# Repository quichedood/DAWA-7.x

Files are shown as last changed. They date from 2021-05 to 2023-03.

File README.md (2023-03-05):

# DAWA-7.x

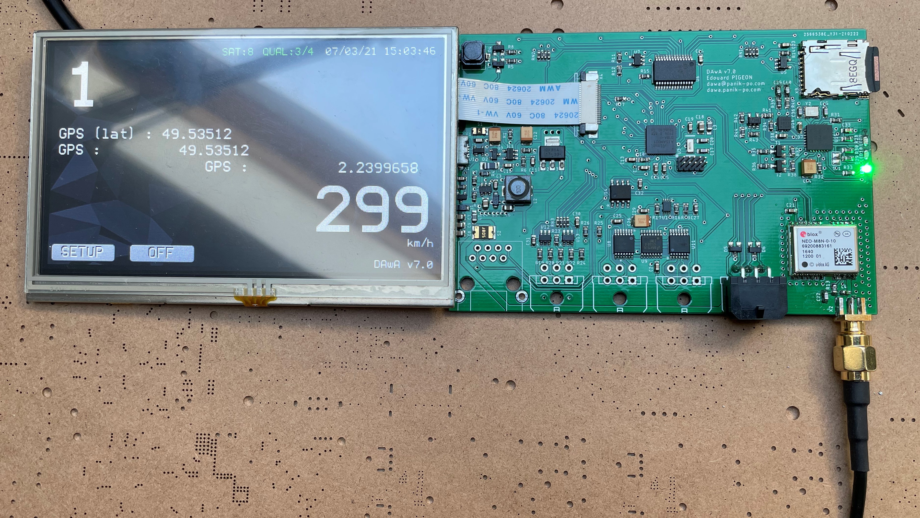
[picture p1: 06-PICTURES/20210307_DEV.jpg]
DAWA7


Démo : https://youtu.be/l66AxoFr9uk

DAWA est un système de chronométrage et d'acquisition de données pour votre moto.
Il enregistre les données 10 fois par seconde dans un fichier CSV.

Specs/fonctionnalités :
- Ecran TFT tactile 4,3" couleur (resistif)
- Carte micro SD
- Antenne GPS externe
- Alimentation externe via batterie 12v
- Indicateur 8 leds paramétrable
- Position GPS (10Hz)
- Chronométrage circuit
- 2 entrées numériques (binaire)
- 2 entrées numériques (signal carré, fréquence)
- 8 entrées analogiques
- 6 capteurs de température infrarouge
- Module OBD (prise diagnostique)

Exemple de mesures :
- Vitesse (GPS ou basé sur une entrée numérique)
- Rapport de vitesse engagé (basé sur une entrée analogique)
- Régime moteur (basé sur une entrée numérique)
- Capteur de pression de frein (basé sur une entrée analogique)

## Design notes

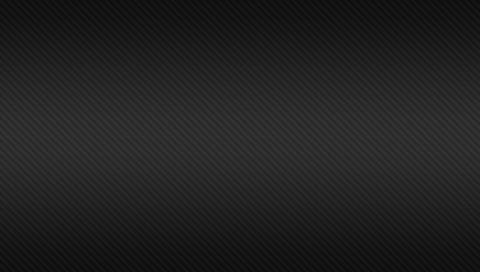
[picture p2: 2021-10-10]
05-EVE/EAB/Pictures/carbon_480x272_COMPRESSED_RGBA_ASTC_4x4_KHR_Converted.png

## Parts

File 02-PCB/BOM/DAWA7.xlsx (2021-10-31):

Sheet: Feuil1
Qty | Stock Perso | Ex | Line Item | Manufacturer | MPN | Schematic Reference | Description | Unit price Mouser | Stock Mouser | Datasheet
1 | 7 | 7 | LM2734YMK/NOPB | Texas Instruments | LM2734YMK/NOPB | U2 |  | !!! Processing !!! | !!! Processing !!! | !!! Processing !!!
1 | 9 | 9 | ADC128D818CIMTX/NOPB | Texas Instruments | ADC128D818CIMTX/NOPB | U9 |  | !!! Processing !!! | !!! Processing !!! | !!! Processing !!!
1 | 15 | 15 | SKPMAPE010 | ALPS | SKPMAPE010 | S3 |  | !!! Processing !!! | !!! Processing !!! | !!! Processing !!!
1 | 50 | 50 | 0432028816 | Molex | 43202-8816 | X6 |  | !!! Processing !!! | !!! Processing !!! | !!! Processing !!!
1 | 6 | 6 | MCP2562T-E/MF | Microchip | MCP2562T-E/MF | U16 | 1/1 Transceiver Half CANbus 8-DFN (3x3) | !!! Processing !!! | !!! Processing !!! | ERROR: Unauthorized Access. Please email contact@octopart.com for assistance.
1 | 20 | 20 | MC33269ST-3.3T3G | ON Semiconductor | MC33269ST-3.3T3G | IC2 | Adjustable Output Low Dropout Voltage Regulator 800 mA | !!! Processing !!! | !!! Processing !!! | !!! Processing !!!
1 | 0 | 0 | ATSAMD21G18A-MFT | Microchip | ATSAMD21G18A-MFT | U3 | Atmel SAMD21G SMART ARM-Based Microcontroller | !!! Processing !!! | !!! Processing !!! | !!! Processing !!!
1 | 9 | 9 | PESD1CAN,215 | Nexperia | PESD1CAN,215 | D6 | CAN bus ESD protection diode | !!! Processing !!! | !!! Processing !!! | !!! Processing !!!
2 | 18 | 9 | C0603C561J5GACTU | KEMET | C0603C561J5GACTU | C39, C40 | CAPACITOR, European symbol | !!! Processing !!! | !!! Processing !!! | !!! Processing !!!
6 | 100 | 16 | C0805C106K4PAC7210 | KEMET | C0805C106K4PAC7210 | C4, C6, C7, C8, C9, C18 | CAPACITOR, European symbol | !!! Processing !!! | !!! Processing !!! | !!! Processing !!!
4 | 100 | 25 | C0603C220K4GACTU | KEMET | C0603C220K4GACTU | C17, C20, C35, C36 | CAPACITOR, European symbol | !!! Processing !!! | !!! Processing !!! | !!! Processing !!!
16 | 500 | 31 | C0603C104M4RAC7411 | KEMET | C0603C104M4RAC7411 | C10, C11, C13, C14, C15, C16, C19, C23, C24, C25, C28, C29, C30, C31, C32, C33 | CAPACITOR, European symbol | !!! Processing !!! | !!! Processing !!! | !!! Processing !!!
3 | 100 | 33 | C0603C103K3RAC7411 | KEMET | C0603C103K3RAC7411 | C1, C3, C5 | CAPACITOR, European symbol | !!! Processing !!! | !!! Processing !!! | !!! Processing !!!
2 | 100 | 50 | C0603C105K4RAC7411 | KEMET | C0603C105K4RAC7411 | C37, C38 | CAPACITOR, European symbol | !!! Processing !!! | !!! Processing !!! | !!! Processing !!!
1 | 100 | 100 | C0603C475K9PAC7411 | KEMET | C0603C475K9PAC7411 | C21 | CAPACITOR, European symbol | !!! Processing !!! | !!! Processing !!! | !!! Processing !!!
1 | 100 | 100 | C0603C470G3HACTU | KEMET | C0603C470G3HACTU | C22 | CAPACITOR, European symbol | !!! Processing !!! | !!! Processing !!! | !!! Processing !!!
1 | 100 | 100 | C0603C101K5GACTU | KEMET | C0603C101K5GACTU | C27 | CAPACITOR, European symbol | !!! Processing !!! | !!! Processing !!! | !!! Processing !!!
1 | 10 | 10 | CM7V-T1A-32.768kHz-9pF-100PPM-TA-QC | Micro Crystal | CM7V-T1A-32.768KHZ-9PF-100PPM-TA-QC | Y1 | CM7V-T1A Tuning Fork Crystal 32.768 kHz | !!! Processing !!! | !!! Processing !!! | !!! Processing !!!
1 | 10 | 10 | DM3AT-SF-PEJM5 | Hirose | DM3AT-SF-PEJM5 | X3 | CONN MICRO SD R/A PUSH-PUSH SMD | !!! Processing !!! | !!! Processing !!! | !!! Processing !!!
1 | 10 | 10 | 3000TR | Keystone | 3000TR | B1 | CR1216/CR1220/CR1225 12mm 3V lithium coin cell | !!! Processing !!! | !!! Processing !!! | !!! Processing !!!
2 | 100 | 50 | 742C083101JP | CTS Components | 742C083101JP | RN1, RN2 | CTS 742 Series | !!! Processing !!! | !!! Processing !!! | !!! Processing !!!
1 | 100 | 100 | 742C083511JP | CTS Components | 742C083511JP | RN3 | CTS 742 Series | !!! Processing !!! | !!! Processing !!! | !!! Processing !!!
2 | 9 | 4 | MBR120ESFT3G | ON Semiconductor | MBR120ESFT3G | D1, D3 | Diode | !!! Processing !!! | !!! Processing !!! | !!! Processing !!!
1 | 9 | 9 | CD1206-S01575 | Bourns | CD1206-S01575 | D2 | DIODE | !!! Processing !!! | !!! Processing !!! | !!! Processing !!!
1 | 20 | 20 | P82B96DR | Texas Instruments | P82B96DR | U14 | DUAL BIDIRECTIONAL BUS BUFFER | !!! Processing !!! | !!! Processing !!! | !!! Processing !!!
1 | 0 | 0 | MMBZ27VALT3G | ON Semiconductor | MMBZ27VALT3G | D5 | Dual Common Anode Zeners | !!! Processing !!! | ERROR: Unauthorized Access. Please email contact@octopart.com for assistance. | !!! Processing !!!
2 | 14 | 7 | SN74LVC2G17DBVR | Texas Instruments | SN74LVC2G17DBVR | U12, U13 | DUAL SCHMITT-TRIGGER BUFFER | !!! Processing !!! | !!! Processing !!! | !!! Processing !!!
1 | 20 | 20 | 687120149022 | Würth Elektronik | 687120149022 | X4 | FFC/FPC-to-Board 0.50mm (.020p) SMT Top Contact | !!! Processing !!! | !!! Processing !!! | !!! Processing !!!
1 | 7 | 7 | LMV321M5X/NOPB | Texas Instruments | LMV321M5X/NOPB | IC1 | General Purpose, Low Voltage, Rail-to-Rail Output Operational Amplifiers | !!! Processing !!! | !!! Processing !!! | !!! Processing !!!
1 | 10 | 10 | MCP23017-E/SS | Microchip | MCP23017-E/SS | U6 | http://ww1.microchip.com/downloads/en/DeviceDoc/21952a.pdf | !!! Processing !!! | !!! Processing !!! | !!! Processing !!!
1 | 8 | 8 | PRTR5V0U2X,215 | Nexperia | PRTR5V0U2X,215 | U1 | I2C-Bus EDS Protection | !!! Processing !!! | !!! Processing !!! | !!! Processing !!!
1 | 18 | 18 | LQG18HN27NJ00D | Murata | LQG18HN27NJ00D | L4 | INDUCTOR | !!! Processing !!! | !!! Processing !!! | !!! Processing !!!
1 | 7 | 7 | SRR0604-100ML | Bourns | SRR0604-100ML | L2 | INDUCTOR, American symbol | !!! Processing !!! | !!! Processing !!! | !!! Processing !!!
11 | 500 | 45 | 150060VS55040 | Würth Elektronik | 150060VS55040 | LED1, LED2, LED3, LED4, LED5, LED6, LED7, LED8, LED9, LED10, LED11 | LED | !!! Processing !!! | !!! Processing !!! | !!! Processing !!!
4 | 8 | 2 | 43045-0600 | Molex | 43045-0600 | X5, X7, X8, X9 | Molex - Micro-Fit 3.0 Series connector, 3.00mm (0.118p) pitch header, 6 positions. | !!! Processing !!! | !!! Processing !!! | !!! Processing !!!
1 | 15 | 15 | FDN340P | ON Semiconductor | FDN340P | Q3 | MOS FET | !!! Processing !!! | !!! Processing !!! | !!! Processing !!!
1 | 100 | 100 | SI2369DS-T1-GE3 | Vishay | SI2369DS-T1-GE3 | Q1 | MOSFET -30V 29mOhm@-10V -7.6A P-CH | !!! Processing !!! | !!! Processing !!! | !!! Processing !!!
1 | 4 | 4 | STN2100 | Scantool.net |  | U15 | Multiprotocol OBD to UART Interpreter IC | N/A | N/A | N/A
1 | 100 | 100 | BSS123 | ON Semiconductor | BSS123 | Q2 | N-CHANNEL MOS FET | !!! Processing !!! | !!! Processing !!! | !!! Processing !!!
2 | 0 | 0 | MMBT2222ALT1G | ON Semiconductor | MMBT2222ALT1G | T1, T2 | NPN Transistror | !!! Processing !!! | !!! Processing !!! | !!! Processing !!!
2 | 5 | 2 | TLV2374IPWR | Texas Instruments | TLV2374IPWR | U8, U11 | OPERATIONAL AMPLIFIERS | !!! Processing !!! | !!! Processing !!! | !!! Processing !!!
1 | 8 | 8 | PCB from JLCPCB | JLCPCB |  |  | PCB from JLCPCB | N/A | N/A | N/A
1 | 20 | 20 | M50-3500542 | Harwin | M50-3500542 | J1 | PIN HEADER | !!! Processing !!! | !!! Processing !!! | !!! Processing !!!
1 | 0 | 0 | TAJT105K016RNJ | AVX | TAJT105K016RNJ | C26 | POLARIZED CAPACITOR, European symbol | !!! Processing !!! | !!! Processing !!! | !!! Processing !!!
3 | 13 | 4 | TAJB106K025RNJ | AVX | TAJB106K025RNJ | C2, C12, C34 | POLARIZED CAPACITOR, European symbol | !!! Processing !!! | !!! Processing !!! | !!! Processing !!!
1 | 0 | 0 | MF-NSMF050-2 | Bourns | MF-NSMF050-2 | S1 | PTC Resettable Fuses | ERROR: Unauthorized Access. Please email contact@octopart.com for assistance. | !!! Processing !!! | !!! Processing !!!
1 | 16 | 16 | MF-MSMF050-2 | Bourns | MF-MSMF050-2 | S2 | PTC Resettable Fuses | !!! Processing !!! | !!! Processing !!! | !!! Processing !!!
1 | 9 | 9 | TSX-3225 16.0000MF18X-AC3 | Epson | TSX-3225 16.0000MF18X-AC3 | Y2 | Quartz Crystals (MHz) SMD: | !!! Processing !!! | !!! Processing !!! | !!! Processing !!!
2 | 0 | 0 | CRCW0603510RJNEAHP | Vishay | CRCW0603510RJNEAHP | R35, R36 | RESISTOR, European symbol | ERROR: Unauthorized Access. Please email contact@octopart.com for assistance. | !!! Processing !!! | !!! Processing !!!
6 | 0 | 0 | CRCW06034K70FKEA | Vishay | CRCW06034K70FKEA | R11, R12, R16, R17, R19, R20 | RESISTOR, European symbol | !!! Processing !!! | !!! Processing !!! | ERROR: Unauthorized Access. Please email contact@octopart.com for assistance.
10 | 30 | 3 | CRCW060310K0FKEA | Vishay | CRCW060310K0FKEA | R1, R7, R10, R14, R15, R27, R41, R42, R43, R44 | RESISTOR, European symbol | !!! Processing !!! | !!! Processing !!! | !!! Processing !!!
8 | 100 | 12 | CRCW06031K00FKEA | Vishay | CRCW06031K00FKEA | R23, R24, R25, R26, R32, R34, R37, R38 | RESISTOR, European symbol | !!! Processing !!! | !!! Processing !!! | !!! Processing !!!
6 | 100 | 16 | CRCW0603100KFKEAC | Vishay | CRCW0603100KFKEAC | R2, R3, R6, R9, R30, R31 | RESISTOR, European symbol | !!! Processing !!! | !!! Processing !!! | !!! Processing !!!
5 | 100 | 20 | CRCW0603100RFKEAC | Vishay | CRCW0603100RFKEAC | R28, R29, R33, R39, R40 | RESISTOR, European symbol | !!! Processing !!! | !!! Processing !!! | !!! Processing !!!
2 | 100 | 50 | CRCW06031K80FKEA | Vishay | CRCW06031K80FKEA | R21, R22 | RESISTOR, European symbol | !!! Processing !!! | !!! Processing !!! | !!! Processing !!!
1 | 100 | 100 | CRCW0603330RFKEAC | Vishay | CRCW0603330RFKEAC | R5 | RESISTOR, European symbol | !!! Processing !!! | !!! Processing !!! | !!! Processing !!!
1 | 100 | 100 | CRCW06031M00FKEC | Vishay | CRCW06031M00FKEC | R8 | RESISTOR, European symbol | !!! Processing !!! | !!! Processing !!! | !!! Processing !!!
1 | 100 | 100 | CRCW060310R0FKEAC | Vishay | CRCW060310R0FKEAC | R13 | RESISTOR, European symbol | !!! Processing !!! | !!! Processing !!! | !!! Processing !!!
1 | 100 | 100 | CRCW0603200KFKEAC | Vishay | CRCW0603200KFKEAC | R18 | RESISTOR, European symbol | !!! Processing !!! | !!! Processing !!! | !!! Processing !!!
1 | 100 | 100 | CRCW060352K3FKEA | Vishay | CRCW060352K3FKEA | R4 | RESISTOR, European symbol | !!! Processing !!! | !!! Processing !!! | !!! Processing !!!
1 | 100 | 100 | BAT54C,215 | Nexperia | BAT54C,215 | D4 | Schottky Diodes | !!! Processing !!! | !!! Processing !!! | !!! Processing !!!
1 | 13 | 13 | 24AA02E48T-I/OT | Microchip | 24AA02E48T-I/OT | U7 | Serial EEPROM | !!! Processing !!! | !!! Processing !!! | !!! Processing !!!
1 | 0 | 0 | TL331KDBVRG4 | Texas Instruments | TL331KDBVRG4 | U17 | Single differential Comparator | !!! Processing !!! | !!! Processing !!! | !!! Processing !!!
1 | 10 | 10 | CON-SMA-EDGE-S | RF Solutions | CON-SMA-EDGE-S | X2 | SMA Connector | !!! Processing !!! | !!! Processing !!! | !!! Processing !!!
2 | 20 | 10 | MH2029-300Y | Bourns | MH2029-300Y | L1, L3 | SMD EMI Suppression Ferrite Beads | !!! Processing !!! | !!! Processing !!! | !!! Processing !!!
1 | 1 | 1 | RVT43ALBNWR00 | Riverdi | RVT43ALBNWR00 |  | TFT EVE3 Screen | !!! Processing !!! | !!! Processing !!! | !!! Processing !!!
1 | 8 | 8 | 74AHC1G125GW,125 | Nexperia | 74AHC1G125GW,125 | U5 | TRI-STATE SINGLE BUSS BUFFER | !!! Processing !!! | !!! Processing !!! | !!! Processing !!!
1 | 5 | 5 | NEO-M8Q-0 | u-blox | NEO-M8Q-0 | U4 | u-blox NEO GNSS module | !!! Processing !!! | !!! Processing !!! | !!! Processing !!!
1 | 20 | 20 | 1050170001 | Molex | 105017-0001 | X1 | USB Connectors | !!! Processing !!! | !!! Processing !!! | !!! Processing !!!
1 | 17 | 17 | PCA9306DCUT | Texas Instruments | PCA9306DCUT | U10 | VOLTAGE-LEVEL TRANSLATOR | !!! Processing !!! | !!! Processing !!! | !!! Processing !!!

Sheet: Feuil2
Octopart Add-In is ready

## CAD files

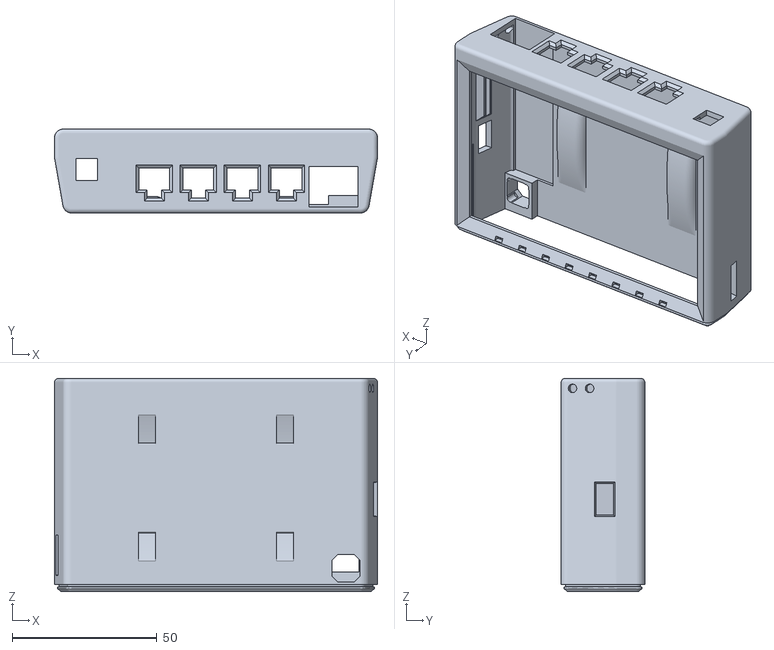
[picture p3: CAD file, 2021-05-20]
04-ENCLOSURE/STL/MAIN-7.0.stl
111.7 x 29.0 x 73.8

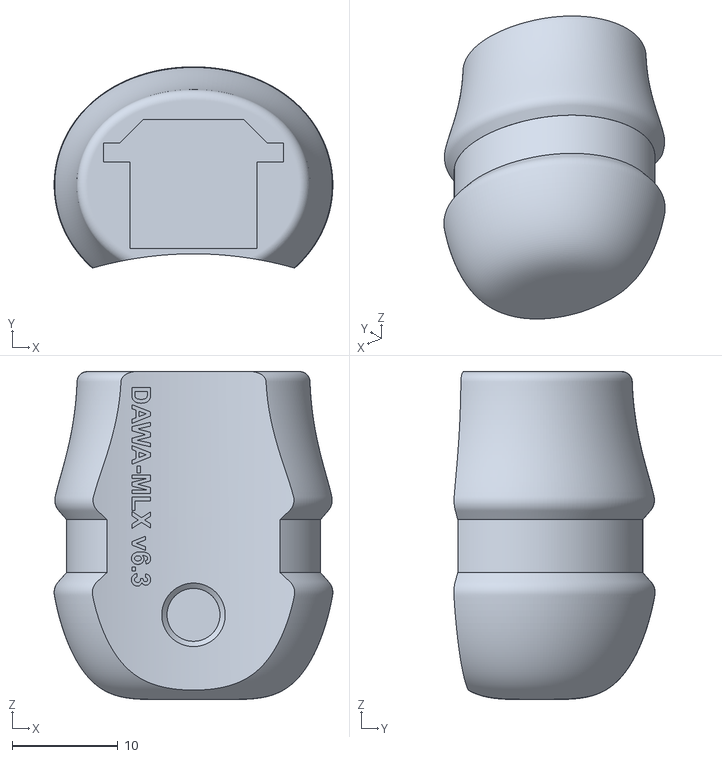
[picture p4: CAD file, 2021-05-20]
04-ENCLOSURE/STL/IRSENSOR-6.3.stl
26.3 x 19.0 x 31.0

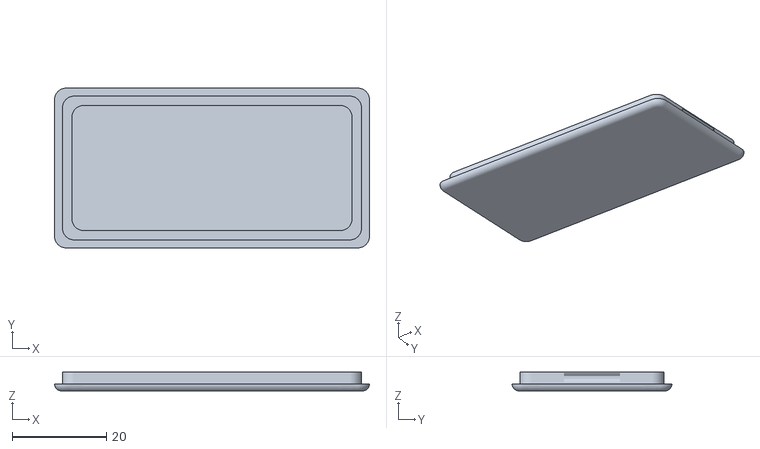
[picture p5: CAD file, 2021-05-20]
04-ENCLOSURE/STL/SWITCH-6.3-PART2.stl
67.0 x 34.0 x 4.00

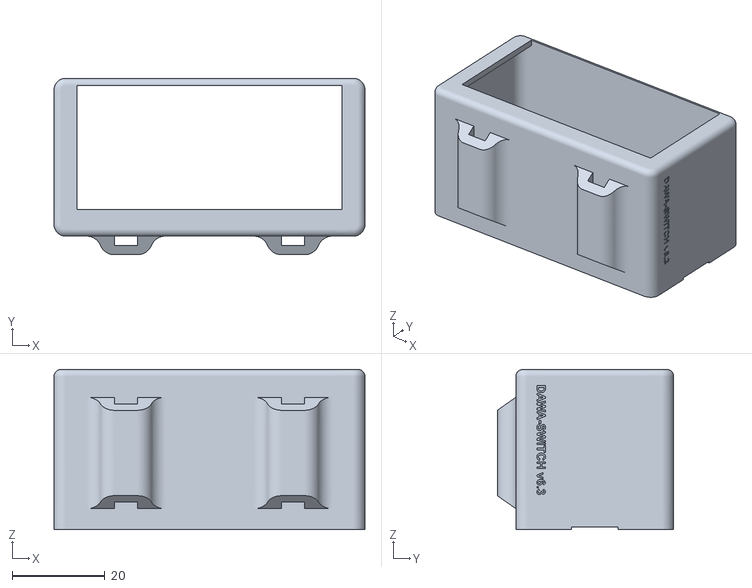
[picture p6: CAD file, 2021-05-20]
04-ENCLOSURE/STL/SWITCH-6.3-PART1.stl
67.0 x 38.0 x 34.5

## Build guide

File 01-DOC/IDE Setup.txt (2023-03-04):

Download and install Visual Studio Code
Open VSCode Extension Manager
Search for official PlatformIO IDE extension
Install PlatformIO IDE

In "Visual Studio Code", go to "PlatformIO/Miscellaneous/PlatformIO Core CLI/" and run :
pio settings set projects_dir "/The/Github/directory/DAWA7/03-DEV"

Edit file : C:\Users\<profilename>\.platformio\packages\framework-arduino-samd\variants\arduino_mzero\variant.cpp
Comment following lines :
//Uart Serial( &sercom5, PIN_SERIAL_RX, PIN_SERIAL_TX, PAD_SERIAL_RX, PAD_SERIAL_TX ) ;
//void SERCOM5_Handler()
//{
//  Serial.IrqHandler();
//}

Restart Visual Studio Code
Open an existant project in PlateformIO

The following changes are only for information as you already download the entire PlatformIO project

#### Timelib Library ####
>TimeLib.h
Rename DAYS_PER_WEEK to DAYS_PER_WEEK_ALT

#### FT800-FT813 Library ####
> EVE_config.h
l.104 : #define EVE_RiTFT43

> EVE_commands.c
Rename to "EVE_commands.cpp"

> tft.cpp
Enable first time calibration, report values above (l.140)
l.232 : #if 0 > #if 1 

> EVE_target.h
#define EVE_CS 		13
#define EVE_PDN		9

#### NeoGPS Library ####
> DMS.h
Comment "class Print;"

> NeoTime.h
Comment "class Print;"

https://github.com/SlashDevin/NeoGPS/pull/153/files

> NeoTime.h
static const uint16_t s_epoch_year = POSIX_EPOCH_YEAR;
static const uint8_t  s_epoch_weekday = POSIX_EPOCH_WEEKDAY;

> NMEAGPS_cfg.h
uncomment #define NMEAGPS_PARSE_PROPRIETARY
uncomment #define NMEAGPS_DERIVED_TYPES

#### ELMDuino Library ####
> ELMduino.cpp
Replace all "Serial." by "DEBUG_PORT."

> ELMduino.h
Add at line 4 : "#define DEBUG_PORT SERIAL_PORT_USBVIRTUAL"

#### MLX90614 Library ####
> Adafruit_MLX90614.cpp
uint8_t Adafruit_MLX90614::readAddr(void) {
  uint8_t addr;

  addr = lowByte(read16(MLX90614_ADDR));
  return addr;
}

void Adafruit_MLX90614::writeAddr(uint8_t addr) {
  write16(MLX90614_ADDR, 0); // erase
  delay(10);
  write16(MLX90614_ADDR, addr);
  delay(10);
}

> Adafruit_MLX90614.h
uint8_t readAddr(void);
void writeAddr(uint8_t addr);

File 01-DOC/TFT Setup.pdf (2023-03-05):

# Implémentation module LCD (BT816/EVE)

# Introduction

Les modules LCD EVE (Embedded Video Engine) permettent de développer des interfaces graphiques évoluées sans pour autant avoir besoin derrière d'une grosse puissance de calcul.

Module utilisé : Riverdi 4.3" Resistive TFT (https://riverdi.com/product/ritft43res/)

Il est équipé d'une puce FTDI BT816 et d'une mémoire flash de 8Mo (64Mb).

# Librairie Arduino

Librairie utilisée pour fonctionner avec un Arduino M0 : Rudolph Riedel FT800-FT813 (https://github.com/RudolphRiedel/FT800-FT813)

Les fichiers de la librairie sont répartis de la sorte :

- Dans un dossier "FT800-FT813" placé le dossier "Librairies" de l'Arduino : EVE.h, EVE_commands.cpp, EVE_commands.h, EVE_config.h, EVE_target.c, EVE_target.h
- Les fichiers tft.cpp, tft.h, tft_data.c et tft_data.h sont directement lié au projet Arduino

Le fichier EVE_config.h doit être modifié pour spécifier le type de LCD utilisé (ligne ~119) :

#define EVE_RiTFT43

# Connexion à l'Arduino M0

Le branchement du LCD à l'Arduino M0 se fait via le port SPI matériel dédié.

LCD (RiBUS) | | Arduino M0
1 | VDD-3.3v | 3.3v
2 | GND | GND
3 | CLK | CLK
4 | MISO | MISO
5 | MOSI | MOSI
6 | CS | D9
8 | RESET | D8
17 | VDD-5V | 5v

Les ports D8 et D9 sont spécifiés dans le fichier EVE_target.h

Pour faciliter les tests, j'utilise un connecteur FFC/FPC 0.5mm 20 pins monté sur un PCB. (https://fr.aliexpress.com/item/4000594877125.html) Attention sur l'exemplaire reçu, la numérotation des pins est inversée selon le coté de lecture du PCB !!

# Utilitaires

## EVE Asset Builder

Matériel et branchements

Attention au sens de la nappe dans les connecteurs

Attention à la nappe utilisée (connecteurs opposés dans mon cas)

Il faut ensuite envoyer ces fichiers vers la mémoire flash du module LCD. Pour cela il faut un petit module permettant de faire l'interface entre le port USB du PC et le bus SPI.

J'utilise le module "UMFT4222EV-D" de "FTDI" (Mouser.fr). (https://www.mouser.fr/ProductDetail/FTDI/UMFT4222EV-D?qs=F5EMLAvA7ICRJCgnkJGADg==&vip=1)

Coté LCD, il faut se baser sur la documentation RiBUS (https://riverdi.com/technologies/ribus/)

LCD (RiBUS) | | UMFT4222EV-D
1 | VDD-3.3v | JP5.2
2 | GND | JP5.3
3 | CLK | JP5.9
4 | MISO | JP5.8
5 | MOSI | JP5.7
6 | CS | JP4.9
8 | RESET | JP5.11
11 | SPI-IO2 | JP5.5
12 | SPI-IO3 | JP5.4
17 | VDD-5V | JP4.2

Convertir les images

Aller dans "IMAGE CONVERTER", ajouter la ou les images que l'on souhaite utiliser grâce au bouton "ADD".

Sélectionner un dossier de destination.

Spécifier le module du LCD (BT81X ici)

Spécifier le format de sortie : "COMPRESSED_RGBA_ASTC_4x4_KHR"

Ne pas cocher la case "Compressed"

Cliquer sur "CONVERT"

Un fichier avec l'extension ".raw" est généré.

Convertir les polices de caractères

Aller dans "GENERATE FONT", ajouter la police que l'on souhaite utiliser grâce au bouton "ADD" (champ "Input Font File").

Définir la taille de la police souhaitée, si plusieurs tailles sont nécessaires il faut faire une conversion par taille.

Sélectionner un dossier de destination.

Sélectionner l'onglet "Extended Format [BT81X]".

Dans "Bitmap Format" sélectionner "ASTC"

Dans "Address Of Glyph Data" sélectionner "FLASH/4096"

Dans "ASTC Block Foorprints" sélectionner "AUTO"

Dans "Compression Speed" sélectionner "thorough"

Sélectionner ensuite les caractères de la police à convertir :

- Tous : "Full Unicode Characters"
- Certains d'entres eux : "Characters To Be Converted" (spécifier un fichier texte contenant les caractères à convertir)

Cliquer sur "CONVERT"

Plusieurs fichiers sont générés, le .glyph et le .xfont nous intéressent.

Générer une image flash

Aller dans "FLASH UTILITIES" puis "Generate Flash Image", cliquer sur "ADD" et ajouter le ou les fichiers .bin générés précédemment.

Les polices seront renseignées en premier (.glyph puis .xfont), ensuite spécifier les images (.raw).

Spécifier le module du LCD (BT815/6 ici)

Cocher la case "Data Alignement"

Sélectionner un dossier de destination et un nom de fichier

Cliquer sur "GENERATE"

Un fichier avec l'extension ".bin" est généré.

Important, les adresses de début et de fin de chaque fichiers sont spécifiées dans la partie "Flash's Map". Ces valeurs seront utilisées par la suite.

unified.blob : 0 : 4096
monoMMM_5_12_ASTC.glyph : 4096 : 129536 monoMMM_5_12_ASTC.xfont : 133632 : 4352 monoMMM_5_16_ASTC.glyph : 137984 : 129536 monoMMM_5_16_ASTC.xfont : 267520 : 4288
monoMMM_5_72_ASTC.glyph : 271808 : 57344
monoMMM_5_72_ASTC.xfont : 329152 : 192 wallpaper_480x272_COMPRESSED_RGBA_ASTC_4x4_KHR.raw : 329344 : 130560

Aller dans "FLASH UTILITIES" puis "Flash Programmer".

Sélectionner le module "FT4222" puis cliquer sur "DETECT" pour vérifier le bon fonctionnement du module.

Cliquer ensuite sur "PROGRAM", sélectionner le dernier fichier .bin généré et cliquer sur "UPDATE".

Malgré les erreurs le fichier est généralement bien écrit dans la mémoire flash. Cela peut être vérifié en lisant la mémoire flash et en comparant le fichier obtenu avec le fichier programmé initialement.

Charger l'ensemble dans le programme

Différentes actions sont nécessaires.

Définir les adresses en RAM des différents éléments à copier.

La première police sera copiée à l'adresse 0.

La deuxième police sera copiée à l'adresse 4352 (c'est la taille qu'occupe le premier fichier .xfont)

La troisième police sera copiée à l'adresse 8640 (c'est la taille qu'occupe le premier + le deuxième fichier .xfont)

L'image sera copiée à l'adresse 8832 (somme de la taille des 3 polices : 4352 + 4288 + 192)

Les fichiers .glyph restent en mémoire flash, ils ne sont pas copiés en RAM !

/* memory-map defines */
#define MEM_FONT_01 0

#define MEM_FONT_02 4352

#define MEM_FONT_02 8640

#define MEM_PICT_01 8832

Il faut ensuite indiquer au programme d'aller lire la mémoire flash de l'écran TFT (dans laquelle on à programmé notre .bin) pour copier le contenu en RAM.

/* init */
EVE_init_flash();
EVE_cmd_flashread(MEM_FONT_01, 133632, 4352); /* copy from FLASH (read 4288 bits starting offset 84608) to G-RAM (MEM_FONT_01/.xfont) */
EVE_cmd_flashread(MEM_FONT_02, 267520, 4288);
EVE_cmd_flashread(MEM_FONT_03, 329152, 192);
EVE_cmd_flashread(MEM_PICT_01, 329344, 130560);

Enfin, les données peuvent être utilisées, ici à l'initialisation :

/* init background */
[...]
EVE_cmd_setbitmap(MEM_PICT_01, EVE_COMPRESSED_RGBA_ASTC_4x4_KHR, 480, 272); [...]
EVE_cmd_setfont2(12, MEM_FONT_01, 32);
EVE_cmd_setfont2(13, MEM_FONT_02, 32);
EVE_cmd_setfont2(14, MEM_FONT_03, 32);
EVE_cmd_text_var(EVE_HSIZE - 10, EVE_VSIZE - 15, 12, EVE_OPT_RIGHTX, LABEL_VERSION, 0);

Les polices personnalisées peuvent être attribuées à des "slots" prévus à cet effet (12, 13, 14 ici).

## EVE Screen Editor

Cet utilitaire permet de réaliser le design en faisant des drag&drop des différents éléments souhaités (couleurs, textes, images, etc) puis de générer automatiquement le code associé.

Attention, le code généré convient à l'environnement de développement proposé par Bridgetek et non à la librairie utilisée avec l'Arduino. Néanmoins les commandes sont très similaires et demandent du coup peu d'adaptation.

## Exemples

Afficher un bouton

EVE_cmd_dl(DL_COLOR_RGB | WHITE);
EVE_cmd_fgcolor(0x00c0c0c0); /* some grey */
EVE_cmd_dl(TAG(10)); /* assign tag-value '10' to the button that follows */ EVE_cmd_button(20, 20, 80, 30, 28, toggle_state, "Touch!"); EVE_cmd_dl(TAG(0)); /* no touch */

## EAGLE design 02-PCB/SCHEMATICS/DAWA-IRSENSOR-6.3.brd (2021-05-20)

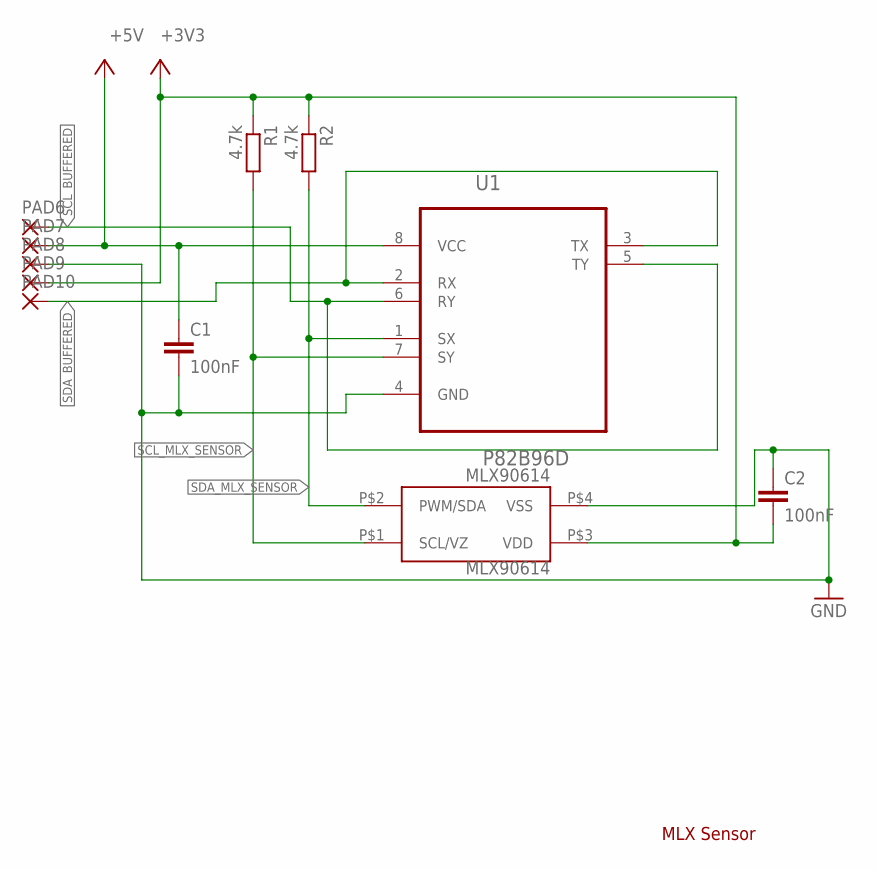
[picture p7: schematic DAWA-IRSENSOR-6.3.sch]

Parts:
C1, C2: 100nF; C0603
MLX90614: MLX90614; TO-39
PAD6, PAD7, PAD8, PAD9, PAD10: WIREPAD1,6/0,9; 1,6/0,9
R1, R2: 4.7k; R0603
U1: P82B96D; SOIC127P600X175-8N

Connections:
+3V3: C2.2, MLX90614.P$3 (VDD), PAD9.1, R1.1, R2.1
+5V: C1.1, PAD7.1, U1.8 (VCC)
GND: C1.2, C2.1, MLX90614.P$4 (VSS), PAD8.1, U1.4 (GND)
SCL_BUFFERED: PAD6.1, U1.5 (TY), U1.6 (RY)
SCL_MLX_SENSOR: MLX90614.P$1 (SCL/VZ), R1.2, U1.7 (SY)
SDA_BUFFERED: PAD10.1, U1.2 (RX), U1.3 (TX)
SDA_MLX_SENSOR: MLX90614.P$2 (PWM/SDA), R2.2, U1.1 (SX)

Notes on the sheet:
MLX Sensor

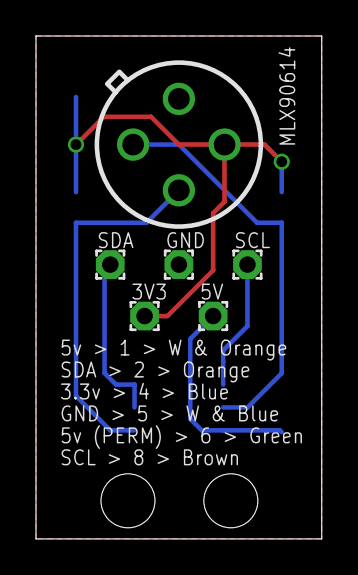
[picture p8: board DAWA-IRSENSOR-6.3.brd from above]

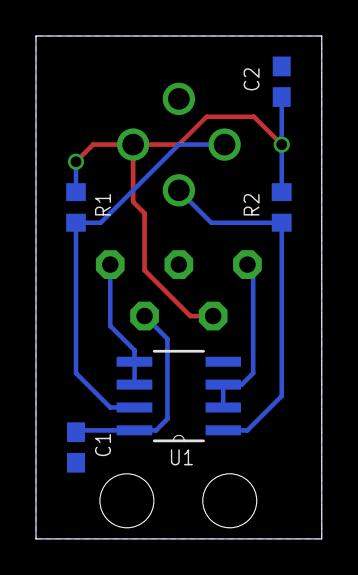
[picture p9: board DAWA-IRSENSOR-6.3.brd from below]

Board: 2 copper layers, 15.9 x 27.9 mm, 11 parts (5 on the bottom side), 7 nets.

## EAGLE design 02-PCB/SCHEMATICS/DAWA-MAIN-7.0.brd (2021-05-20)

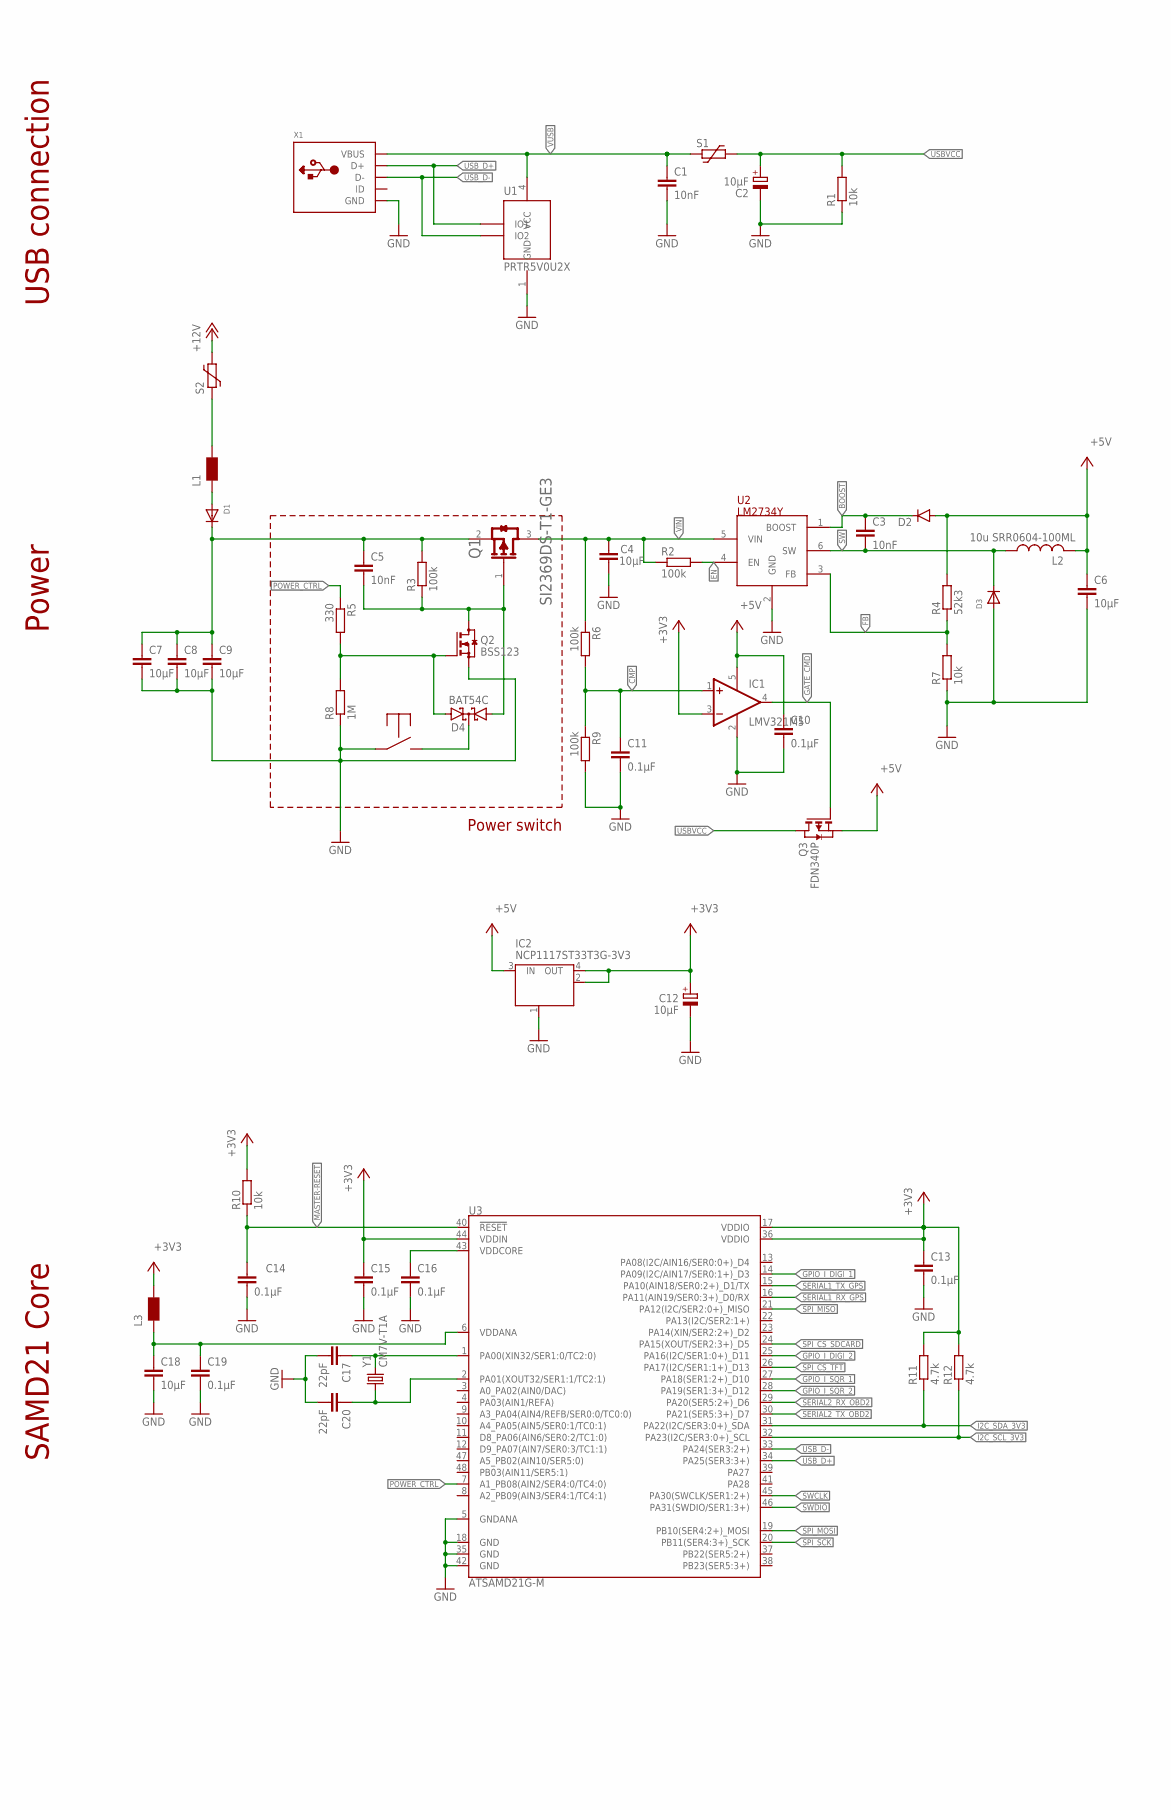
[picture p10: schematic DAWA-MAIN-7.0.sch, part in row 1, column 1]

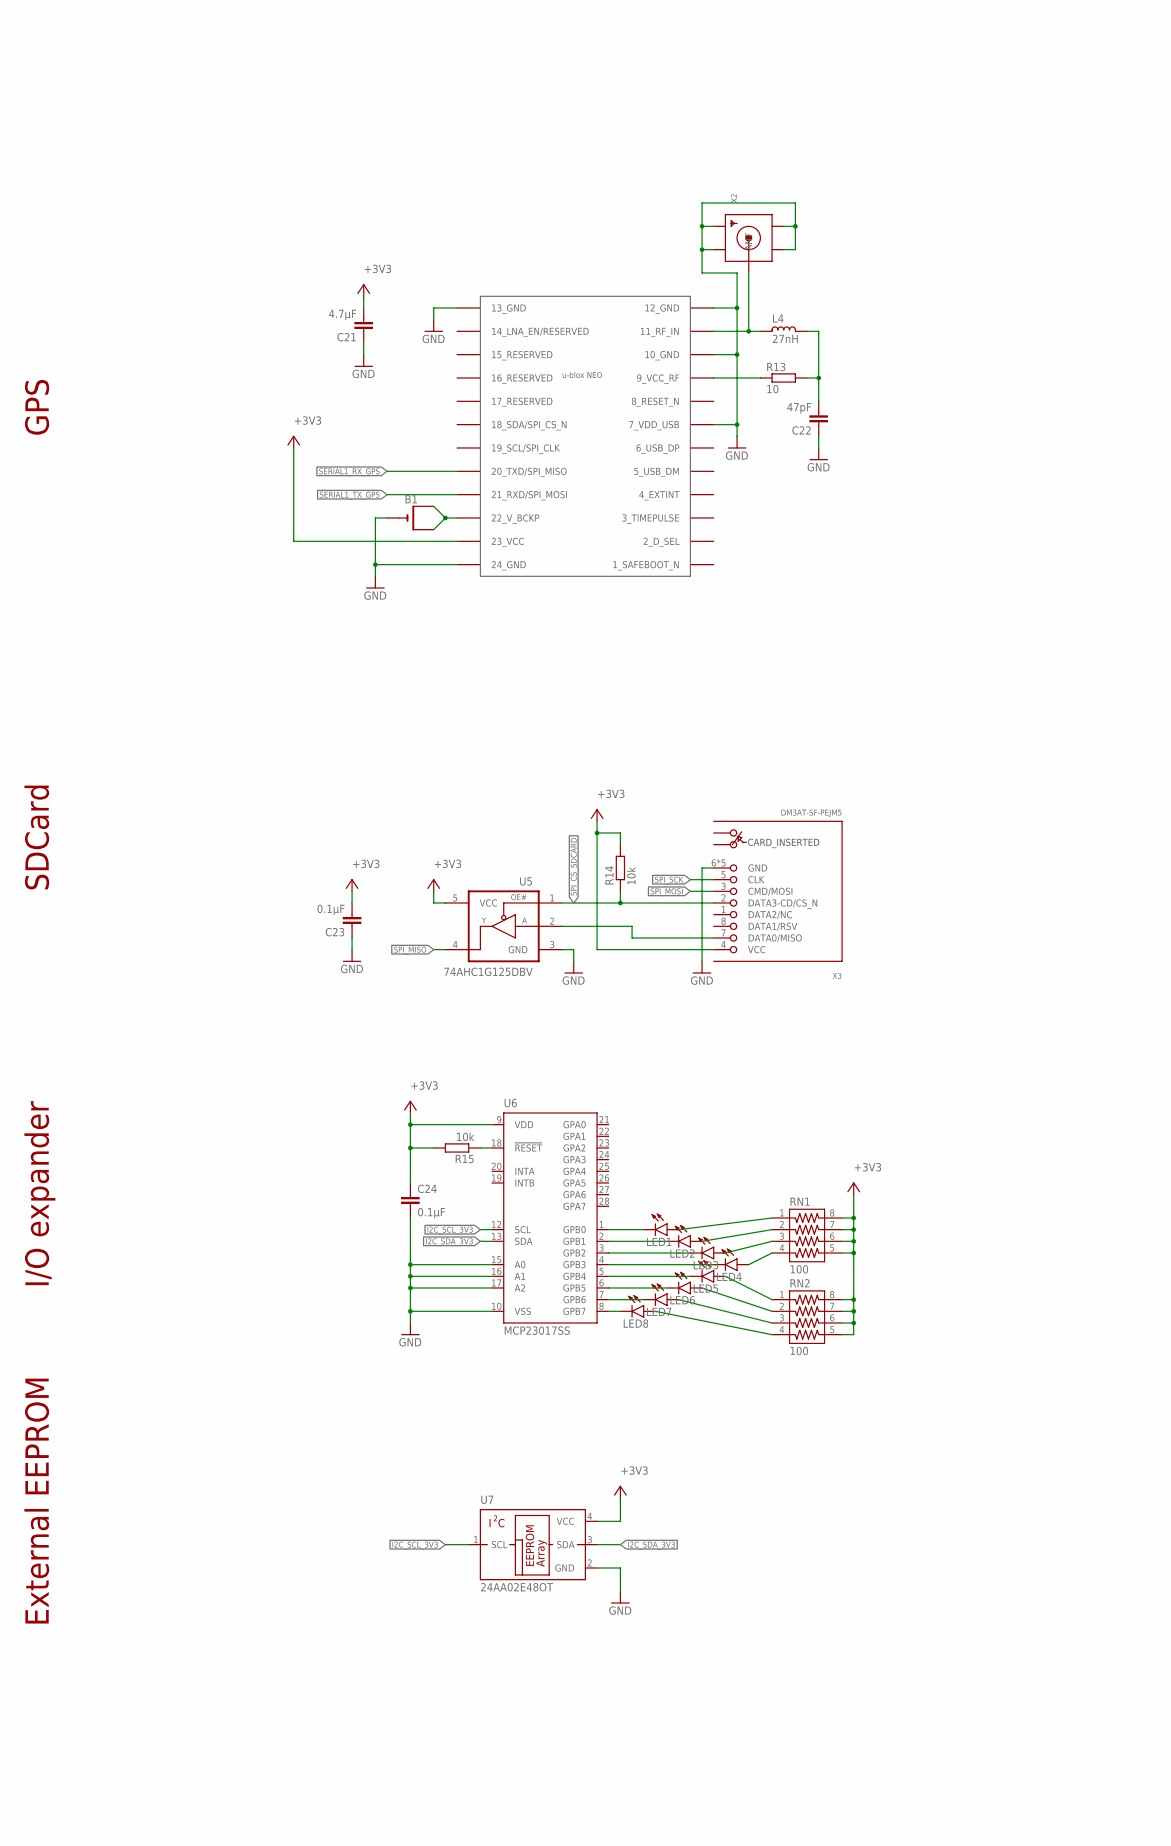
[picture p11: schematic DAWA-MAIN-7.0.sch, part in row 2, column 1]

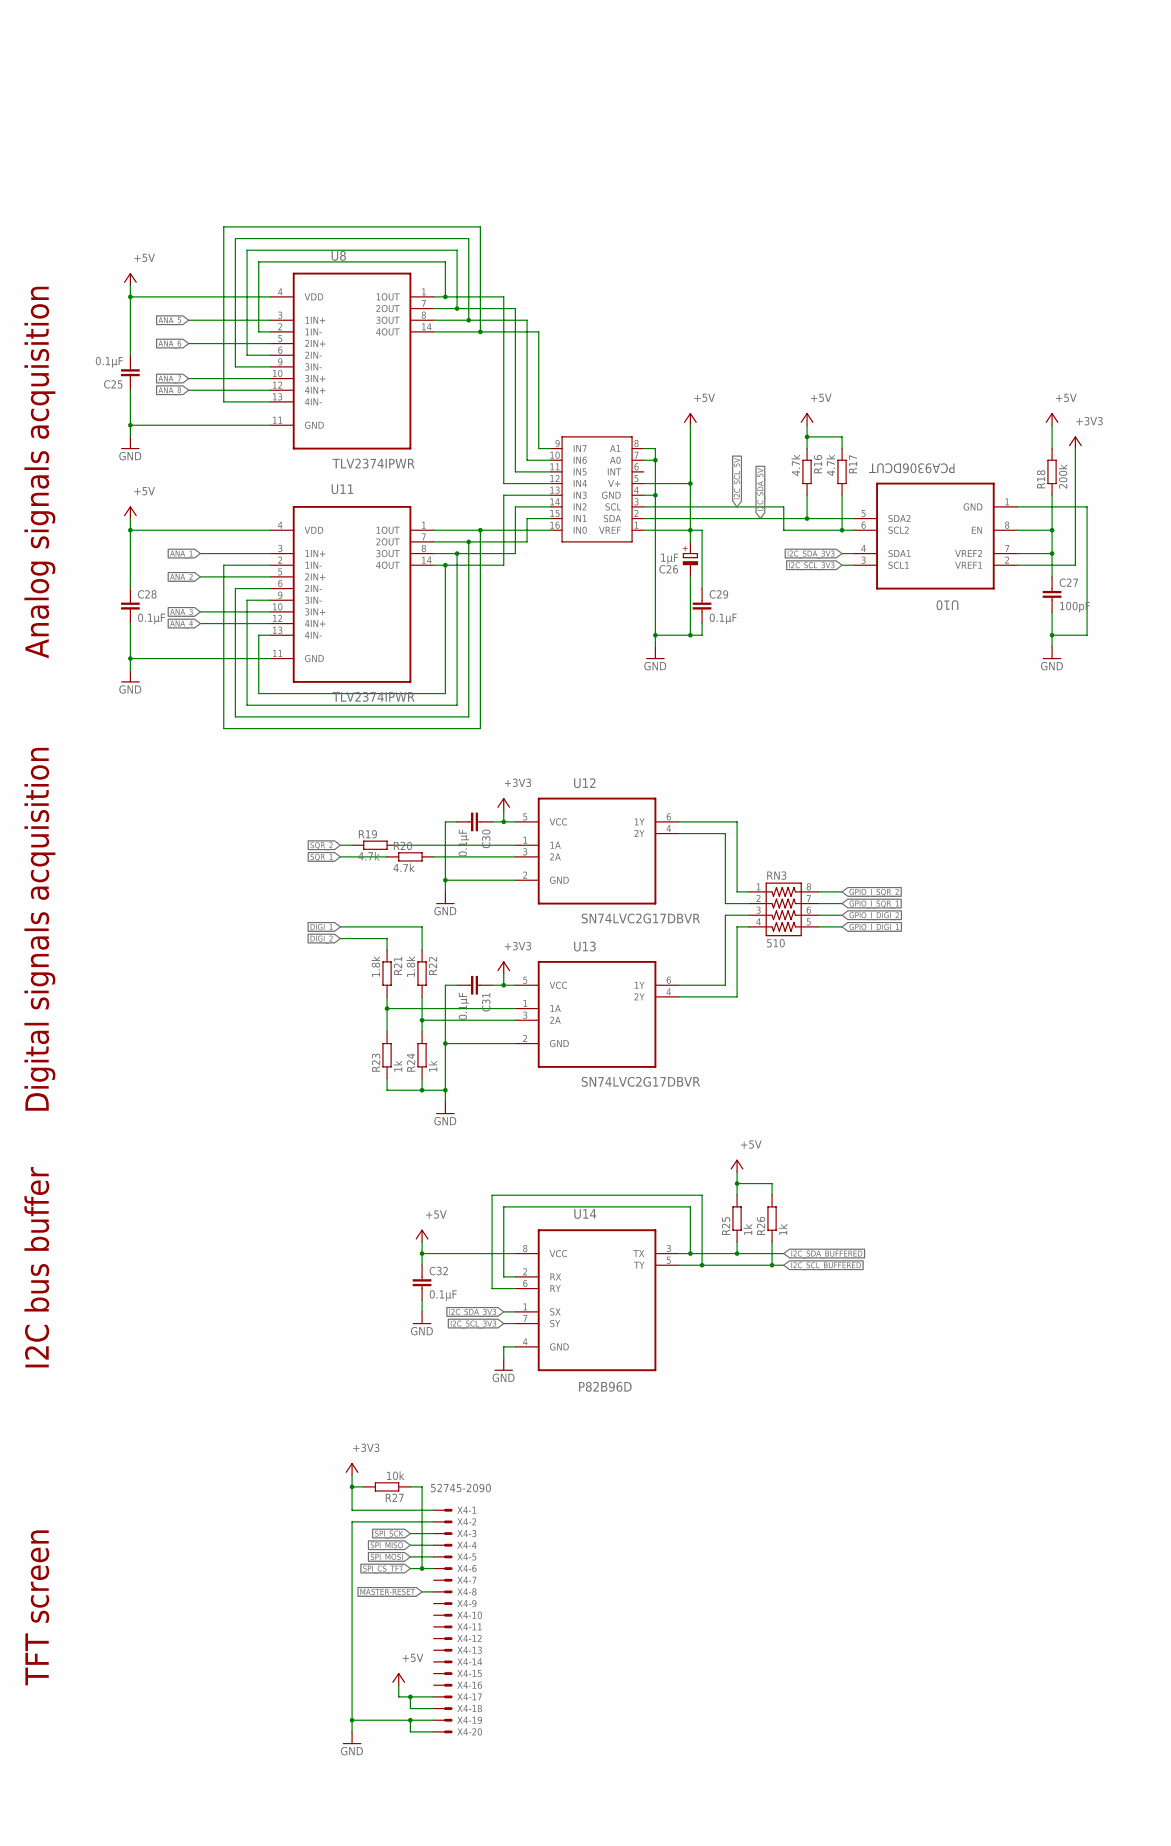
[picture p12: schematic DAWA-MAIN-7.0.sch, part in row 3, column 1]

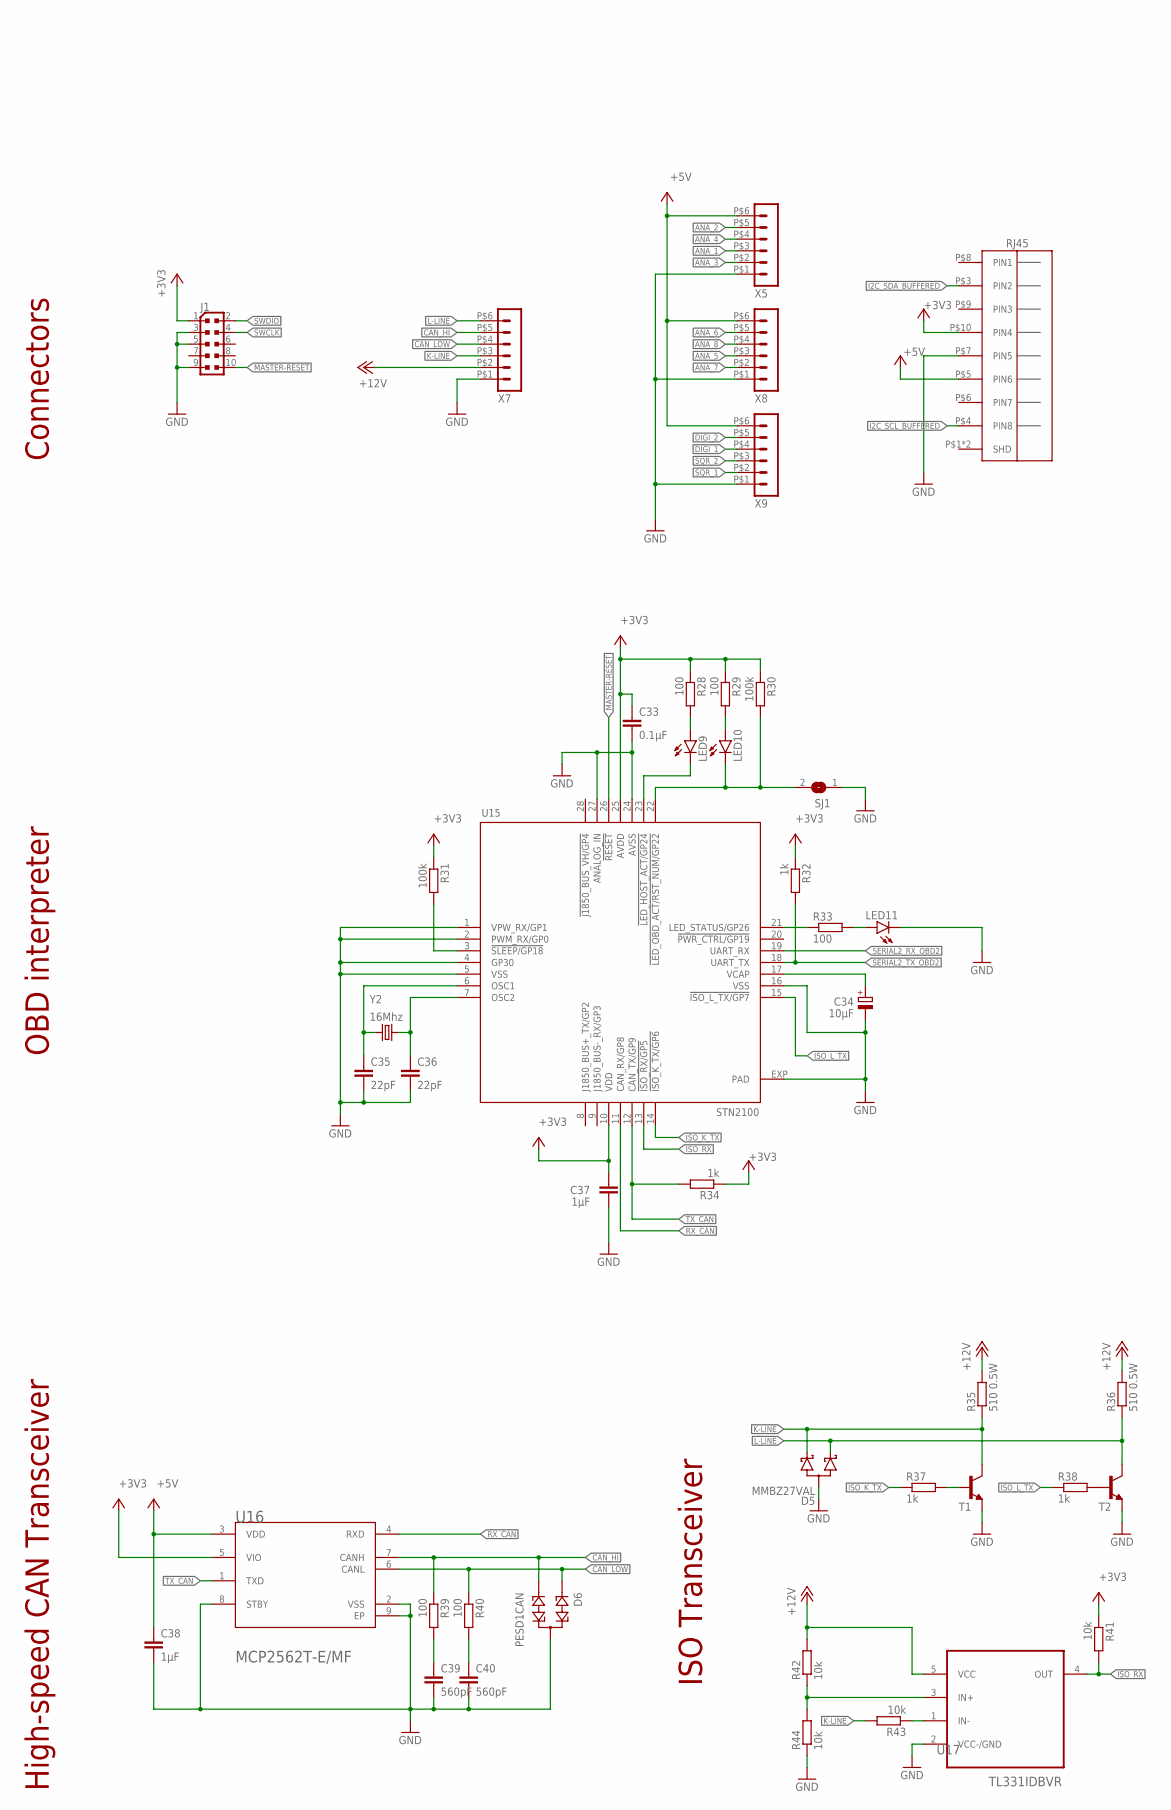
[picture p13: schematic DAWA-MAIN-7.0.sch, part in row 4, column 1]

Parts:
B1: CR1220SMT; CR1220-SMD
C1, C3, C5: 10nF; C0603
C2, C12, C34: 10µF; SMC_B
C4, C6, C7, C8, C9, C18: 10µF; C0805
C10, C11, C13, C14, C15, C16, C19, C23, C24, C25, C28, C29, C30, C31, C32, C33: 0.1µF; C0603
C17, C20, C35, C36: 22pF; C0603
C21: 4.7µF; C0603
C22: 47pF; C0603
C26: 1µF; SMC_B
C27: 100pF; C0603
C37, C38: 1µF; C0603
C39, C40: 560pF; C0603
D1, D3: MBR120_SOD-123FL; SOD-123FL
D2: CD1206-S01575MINIMELF; MINIMELF
D4: BAT54C; SOT23
D5: MMBZ27VAL; SOT23
D6: PESD1CAN; SOT23
IC1: LMV321M5; SOT23-5
IC2: NCP1117ST33T3G-3V3; SOT223
J1: PINHD-2X5PASSO127; ARDUINO_WIFI_SHIELD_V018_TG_PINHEAD_2X05_127
L1, L3: MH2029-300Y_0805; WUERTH-ELEKTRONIK_0805
L2: 10u SRR0604-100ML; SRR0604
L4: 27nH; RC-MASTER-SMD_L0603
LED1, LED2, LED3, LED4, LED5, LED6, LED7, LED8, LED9, LED10, LED11: LEDCHIPLED_0603; CHIPLED_0603
Q1: SI2369DS-T1-GE3VISHAY_SI2369DS-T1-GE3_0_0; VISHAY_SI2369DS-T1-GE3_0
Q2: BSS123; SOT23
Q3: FDN340P; SOT-23
R1, R7, R10, R14, R15, R27, R41, R42, R43, R44: 10k; R0603
R2, R3, R6, R9, R30, R31: 100k; R0603
R4: 52k3; R0603
R5: 330; R0603
R8: 1M; R0603
R11, R12, R16, R17, R19, R20: 4.7k; R0603
R13: 10; R0603
R18: 200k; R0603
R21, R22: 1.8k; R0603
R23, R24, R25, R26, R32, R34, R37, R38: 1k; R0603
R28, R29, R33, R39, R40: 100; R0603
R35, R36: 510 0.5W; R0603
RN1, RN2: 100; 742-8NS
RN3: 510; 742-8NS
S1: MF-NSMF050-1206; MF-1206
S2: MF-MSMF050-1812; MF-1812
S3: SKPMAPE10
SJ1: SJ
T1, T2: MMBT2222ALT1-NPN-SOT23-BEC; SOT23-BEC
U1: PRTR5V0U2X; SOT-143B
U2: LM2734Y; SOT23-6
U3: ATSAMD21G-M; QFN-48
U4: NEO-M8
U5: 74AHC1G125DBV; SOT23-5
U6: MCP23017SS; SSOP28
U7: 24AA02E48OT; SOT23-5
U8, U11: TLV2374IPWR; SOP65P640X120-14N
U9: ADC128D818; ADC12_SD
U10: PCA9306DCUT; SOP50P310X90-8N
U12, U13: SN74LVC2G17DBVR; SOT95P280X145-6N
U14: P82B96D; SOIC127P600X175-8N
U15: STN2100; QFN-28-S
U16: MCP2562T-E-MFMICROCHIP_MCP2562T-E-MF_0_2; MICROCHIP_MCP2562T-E-MF_2
U17: TL331IDBVR; SOT95P280X145-5N
X1: USB; USB-MINIB-DAWA
X2: SMACONNECTOR_EDGE; SMA_EDGELAUNCH
X3: DM3AT-SF-PEJM5
X4: 52745-2090
X5, X7, X8, X9: HEADER_POS6_43045-0600; 43045-0600
X6: RJ45
Y1: CM7V-T1A; KANFLO_OSCILLATOR_SMD
Y2: 16Mhz; 3.2X2.5_KX-7

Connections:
+3V3: C12.+, C13.1, C15.1, C21.2, C23.2, C24.1, C30.1, C31.1, C33.1, C37.1, IC1.3 (-IN), IC2.2 (OUT), IC2.4 (OUT), J1.1, L3.2, R10.2, R11.2, R12.2, R14.2, R15.2, R27.2, R28.1, R29.1, R30.1, R31.1, R32.1, R34.1, R41.1, RN1.5, RN1.6, RN1.7, RN1.8, RN2.5, RN2.6, RN2.7, RN2.8, U3.17 (VDDIO), U3.36 (VDDIO), U3.44 (VDDIN), U4.23 (23_VCC), U5.5 (VCC), U6.9 (VDD), U7.4 (VCC), U10.2 (VREF1), U12.5 (VCC), U13.5 (VCC), U15.10 (VDD), U15.25 (AVDD), U16.5 (VIO), X3.4 (VCC), X4.1, X6.P$10 (PIN4)
+5V: C6.1, C10.1, C25.2, C26.+, C28.1, C29.1, C32.1, C38.1, D2.A, IC1.5 (V+), IC2.3 (IN), L2.P$2 (2), Q3.2 (S), R4.2, R16.1, R17.1, R18.2, R25.2, R26.2, U8.4 (VDD), U9.1 (VREF), U9.5 (V+), U11.4 (VDD), U14.8 (VCC), U16.3 (VDD), X4.17, X4.18, X5.P$6 (6), X6.P$5 (PIN6), X8.P$6 (6), X9.P$6 (6)
+12V: R35.2, R36.2, R42.2, S2.1, U17.5 (VCC), X7.P$2 (2)
ANA_1: U11.3 (1IN+), X5.P$3 (3)
ANA_2: U11.5 (2IN+), X5.P$5 (5)
ANA_3: U11.10 (3IN+), X5.P$2 (2)
ANA_4: U11.12 (4IN+), X5.P$4 (4)
ANA_5: U8.3 (1IN+), X8.P$3 (3)
ANA_6: U8.5 (2IN+), X8.P$5 (5)
ANA_7: U8.10 (3IN+), X8.P$2 (2)
ANA_8: U8.12 (4IN+), X8.P$4 (4)
BOOST: C3.1, D2.C, U2.1 (BOOST)
CAN_HI: D6.2, R39.1, U16.7 (CANH), X7.P$5 (5)
CAN_LOW: D6.1, R40.1, U16.6 (CANL), X7.P$4 (4)
CMP: C11.1, IC1.1 (+IN), R6.2, R9.1
DIGI_1: R22.1, X9.P$4 (4)
DIGI_2: R21.1, X9.P$5 (5)
EN: R2.2, U2.4 (EN)
FB: R4.1, R7.2, U2.3 (FB)
GATE_CMD: IC1.4 (OUT), Q3.3 (G)
GND: B1.-, C1.2, C2.-, C4.2, C6.2, C7.2, C8.2, C9.2, C10.2, C11.2, C12.-, C13.2, C14.2, C15.2, C16.2, C17.2, C18.2, C19.2, C20.2, C21.1, C22.1, C23.1, C24.2, C25.1, C26.-, C27.2, C28.2, C29.2, C30.2, C31.2, C32.2, C33.2, C34.-, C35.2, C36.2, C37.2, C38.2, C39.2, C40.2, D3.A, D5.3 (A), D6.3, IC1.2 (V-), IC2.1 (GND/ADJ), J1.3, J1.5, J1.9, LED11.C, Q2.2 (S), R1.1, R7.1, R8.1, R9.2, R23.1, R24.1, R44.1, S3.P$1, SJ1.1, T1.E, T2.E, U1.1 (GND), U2.2 (GND), U3.5 (GNDANA), U3.18 (GND), U3.35 (GND), U3.42 (GND), U4.7 (7_VDD_USB), U4.10 (10_GND), U4.12 (12_GND), U4.13 (13_GND), U4.24 (24_GND), U5.3 (GND), U6.10 (VSS), U6.15 (A0), U6.16 (A1), U6.17 (A2), U7.2 (GND), U8.11 (GND), U9.4 (GND), U9.7 (A0), U9.8 (A1), U10.1 (GND), U11.11 (GND), U12.2 (GND), U13.2 (GND), U14.4 (GND), U15.1 (VPW_RX/GP1), U15.2 (PWM_RX/GP0), U15.4 (GP30), U15.5 (VSS), U15.16 (VSS), U15.24 (AVSS), U15.27 (ANALOG_IN), U15.EXP (PAD), U16.2 (VSS), U16.8 (STBY), U16.9 (EP), U17.2 (VCC-/GND), X1.GND, X1.GND1 (GND), X1.GND2 (GND), X2.GND@1 (GND4), X2.GND@2 (GND3), X2.GND@3 (GND2), X2.GND@4 (GND1), X3.6 (GND), X3.MOUNT0 (GND), X3.MOUNT1 (GND), X3.MOUNT2 (GND), X3.MOUNT3 (GND), X4.2, X4.19, X4.20, X5.P$1 (1), X6.P$7 (PIN5), X7.P$1 (1), X8.P$1 (1), X9.P$1 (1)
GPIO_I_DIGI_1: RN3.5, U3.14 (PA09(I2C/AIN17/SER0:1+)_D3)
GPIO_I_DIGI_2: RN3.6, U3.25 (PA16(I2C/SER1:0+)_D11)
GPIO_I_SQR_1: RN3.7, U3.27 (PA18(SER1:2+)_D10)
GPIO_I_SQR_2: RN3.8, U3.28 (PA19(SER1:3+)_D12)
I2C_SCL_3V3: R12.1, U3.32 (PA23(I2C/SER3:0+)_SCL), U6.12 (SCL), U7.1 (SCL), U10.3 (SCL1), U14.7 (SY)
I2C_SCL_5V: R17.2, U9.3 (SCL), U10.6 (SCL2)
I2C_SCL_BUFFERED: R26.1, U14.5 (TY), U14.6 (RY), X6.P$4 (PIN8)
I2C_SDA_3V3: R11.1, U3.31 (PA22(I2C/SER3:0+)_SDA), U6.13 (SDA), U7.3 (SDA), U10.4 (SDA1), U14.1 (SX)
I2C_SDA_5V: R16.2, U9.2 (SDA), U10.5 (SDA2)
I2C_SDA_BUFFERED: R25.1, U14.2 (RX), U14.3 (TX), X6.P$3 (PIN2)
ISO_K_TX: R37.1, U15.14 (!ISO_K_TX/GP6)
ISO_L_TX: R38.1, U15.15 (!ISO_L_TX/GP7)
ISO_RX: R41.2, U15.13 (!ISO_RX/GP5), U17.4 (OUT)
K-LINE: D5.2 (C2), R35.1, R43.2, T1.C, X7.P$3 (3)
L-LINE: D5.1 (C1), R36.1, T2.C, X7.P$6 (6)
MASTER-RESET: C14.1, J1.10, R10.1, U3.40 (!RESET!), U15.26 (!RESET), X4.8
unnamed: C16.1, U3.43 (VDDCORE)
unnamed: C17.1, U3.1 (PA00(XIN32/SER1:0/TC2:0)), Y1.2
unnamed: C20.1, U3.2 (PA01(XOUT32/SER1:1/TC2:1)), Y1.1
unnamed: LED1.C, U6.1 (GPB0)
unnamed: B1.+$1 (+), B1.+$2 (+1), U4.22 (22_V_BCKP)
unnamed: LED2.C, U6.2 (GPB1)
unnamed: C5.1, C7.1, C8.1, C9.1, D1.C, Q1.2 (S), R3.2
unnamed: LED1.A, RN1.1
unnamed: D1.A, L1.1
unnamed: C22.2, L4.1, R13.2
unnamed: LED2.A, RN1.2
unnamed: U5.2 (A), X3.7 (DATA0/MISO)
unnamed: LED5.C, U6.5 (GPB4)
unnamed: C27.1, R18.1, U10.7 (VREF2), U10.8 (EN)
unnamed: LED6.C, U6.6 (GPB5)
unnamed: LED7.C, U6.7 (GPB6)
unnamed: LED8.C, U6.8 (GPB7)
unnamed: R13.1, U4.9 (9_VCC_RF)
unnamed: L4.2, U4.11 (11_RF_IN), X2.P (ANT)
unnamed: LED3.A, RN1.3
unnamed: LED3.C, U6.3 (GPB2)
unnamed: LED4.C, U6.4 (GPB3)
unnamed: LED4.A, RN1.4
unnamed: LED5.A, RN2.1
unnamed: LED6.A, RN2.2
unnamed: U9.16 (IN0), U11.1 (1OUT), U11.2 (1IN-)
unnamed: U9.15 (IN1), U11.6 (2IN-), U11.7 (2OUT)
unnamed: LED7.A, RN2.3
unnamed: LED8.A, RN2.4
unnamed: U9.14 (IN2), U11.8 (3OUT), U11.9 (3IN-)
unnamed: LED10.C, R30.2, SJ1.2, U15.22 (!LED_OBD_ACT/RST_NUM/GP22)
unnamed: R37.2, T1.B
unnamed: R15.1, U6.18 (!RESET)
unnamed: U9.13 (IN3), U11.13 (4IN-), U11.14 (4OUT)
unnamed: RN3.1, U12.6 (1Y)
unnamed: L1.2, S2.2
unnamed: U8.8 (3OUT), U8.9 (3IN-), U9.10 (IN6)
unnamed: U8.6 (2IN-), U8.7 (2OUT), U9.11 (IN5)
unnamed: U8.1 (1OUT), U8.2 (1IN-), U9.12 (IN4)
unnamed: R19.2, U12.1 (1A)
unnamed: R20.2, U12.3 (2A)
unnamed: R22.2, R24.2, U13.3 (2A)
unnamed: R21.2, R23.2, U13.1 (1A)
unnamed: RN3.3, U13.6 (1Y)
unnamed: RN3.4, U13.4 (2Y)
unnamed: C5.2, D4.1 (A1), Q1.1 (G), Q2.3 (D), R3.1
unnamed: D4.3 (CC), S3.P$2
unnamed: RN3.2, U12.4 (2Y)
unnamed: D4.2 (A2), Q2.1 (G), R5.2, R8.2
unnamed: U8.13 (4IN-), U8.14 (4OUT), U9.9 (IN7)
unnamed: R38.2, T2.B
unnamed: R42.1, R44.2, U17.3 (IN+)
unnamed: R43.1, U17.1 (IN-)
unnamed: R31.2, U15.3 (!SLEEP/GP18)
unnamed: C35.1, U15.6 (OSC1), Y2.1
unnamed: C36.1, U15.7 (OSC2), Y2.3 (2)
unnamed: LED9.A, R28.2
unnamed: C34.+, U15.17 (VCAP)
unnamed: R33.1, U15.21 (LED_STATUS/GP26)
unnamed: LED11.A, R33.2
unnamed: LED10.A, R29.2
unnamed: LED9.C, U15.23 (!LED_HOST_ACT/GP24)
unnamed: C39.1, R39.2
unnamed: C40.1, R40.2
POWER_CTRL: R5.1, U3.7 (A1_PB08(AIN2/SER4:0/TC4:0))
RX_CAN: U15.11 (CAN_RX/GP8), U16.4 (RXD)
SERIAL1_RX_GPS: U3.16 (PA11(AIN19/SER0:3+)_D0/RX), U4.20 (20_TXD/SPI_MISO)
SERIAL1_TX_GPS: U3.15 (PA10(AIN18/SER0:2+)_D1/TX), U4.21 (21_RXD/SPI_MOSI)
SERIAL2_RX_OBD2: U3.29 (PA20(SER5:2+)_D6), U15.19 (UART_RX)
SERIAL2_TX_OBD2: R32.2, U3.30 (PA21(SER5:3+)_D7), U15.18 (UART_TX)
SPI_CS_SDCARD: R14.1, U3.24 (PA15(XOUT/SER2:3+)_D5), U5.1 (OE#), X3.2 (DATA3-CD/CS_N)
SPI_CS_TFT: R27.1, U3.26 (PA17(I2C/SER1:1+)_D13), X4.6
SPI_MISO: U3.21 (PA12(I2C/SER2:0+)_MISO), U5.4 (Y), X4.4
SPI_MOSI: U3.19 (PB10(SER4:2+)_MOSI), X3.3 (CMD/MOSI), X4.5
SPI_SCK: U3.20 (PB11(SER4:3+)_SCK), X3.5 (CLK), X4.3
SQR_1: R20.1, X9.P$2 (2)
SQR_2: R19.1, X9.P$3 (3)
SW: C3.2, D3.C, L2.P$1 (1), U2.6 (SW)
SWCLK: J1.4, U3.45 (PA30(SWCLK/SER1:2+))
SWDIO: J1.2, U3.46 (PA31(SWDIO/SER1:3+))
TX_CAN: R34.2, U15.12 (CAN_TX/GP9), U16.1 (TXD)
USBVCC: C2.+, Q3.1 (D), R1.2, S1.2
USB_D+: U1.2 (IO1), U3.34 (PA25(SER3:3+)), X1.D+
USB_D-: U1.3 (IO2), U3.33 (PA24(SER3:2+)), X1.D-
VDDANA: C18.1, C19.1, L3.1, U3.6 (VDDANA)
VIN: C4.1, Q1.3 (D), R2.1, R6.1, U2.5 (VIN)
VUSB: C1.1, S1.1, U1.4 (VCC), X1.VBUS

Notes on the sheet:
SAMD21 Core
Power
USB connection
GPS
SDCard
I/O expander
Analog signals acquisition
Digital signals acquisition
I2C bus buffer
External EEPROM
Connectors
OBD interpreter
High-speed CAN Transceiver
TFT screen
Power switch
ISO Transceiver

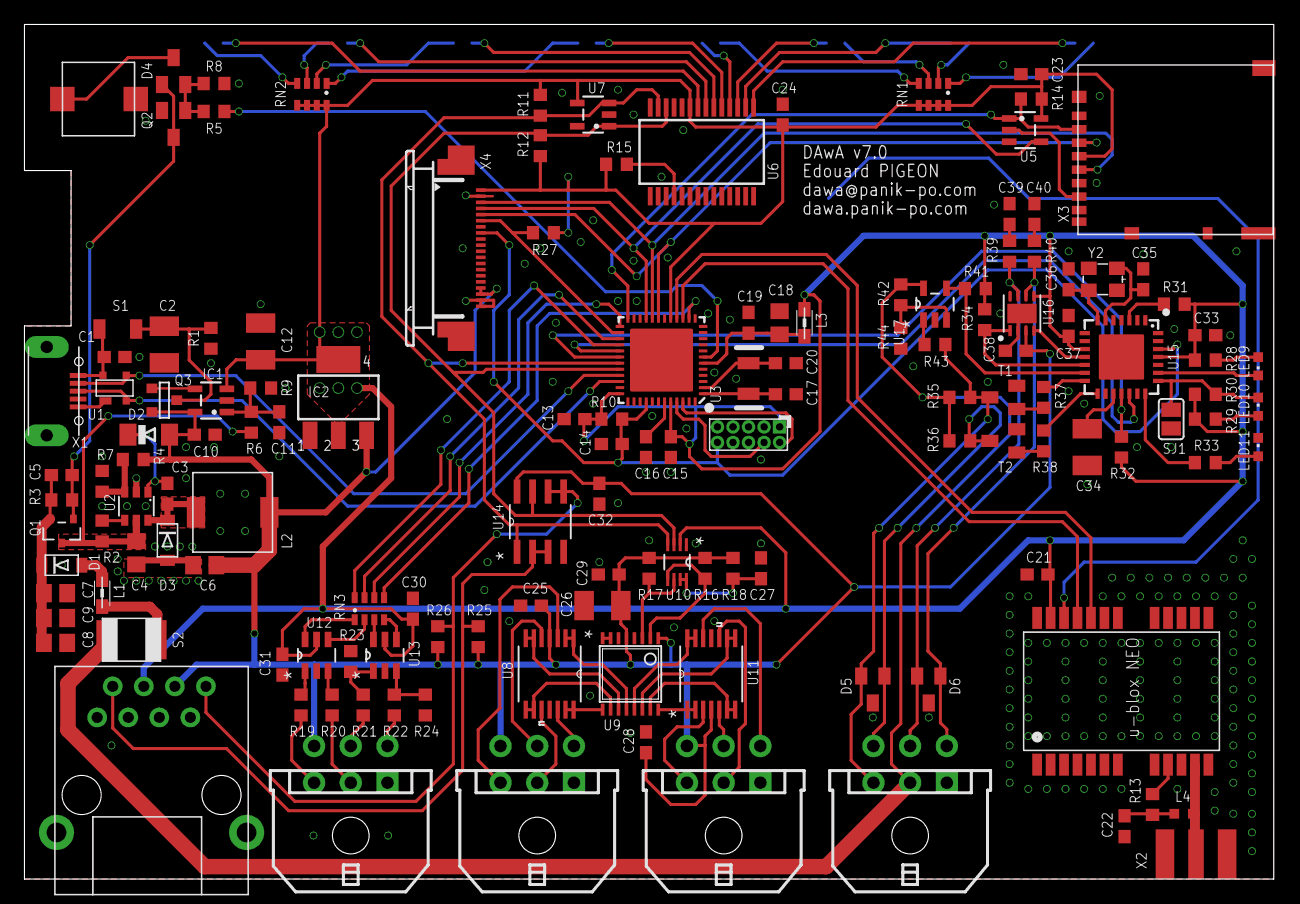
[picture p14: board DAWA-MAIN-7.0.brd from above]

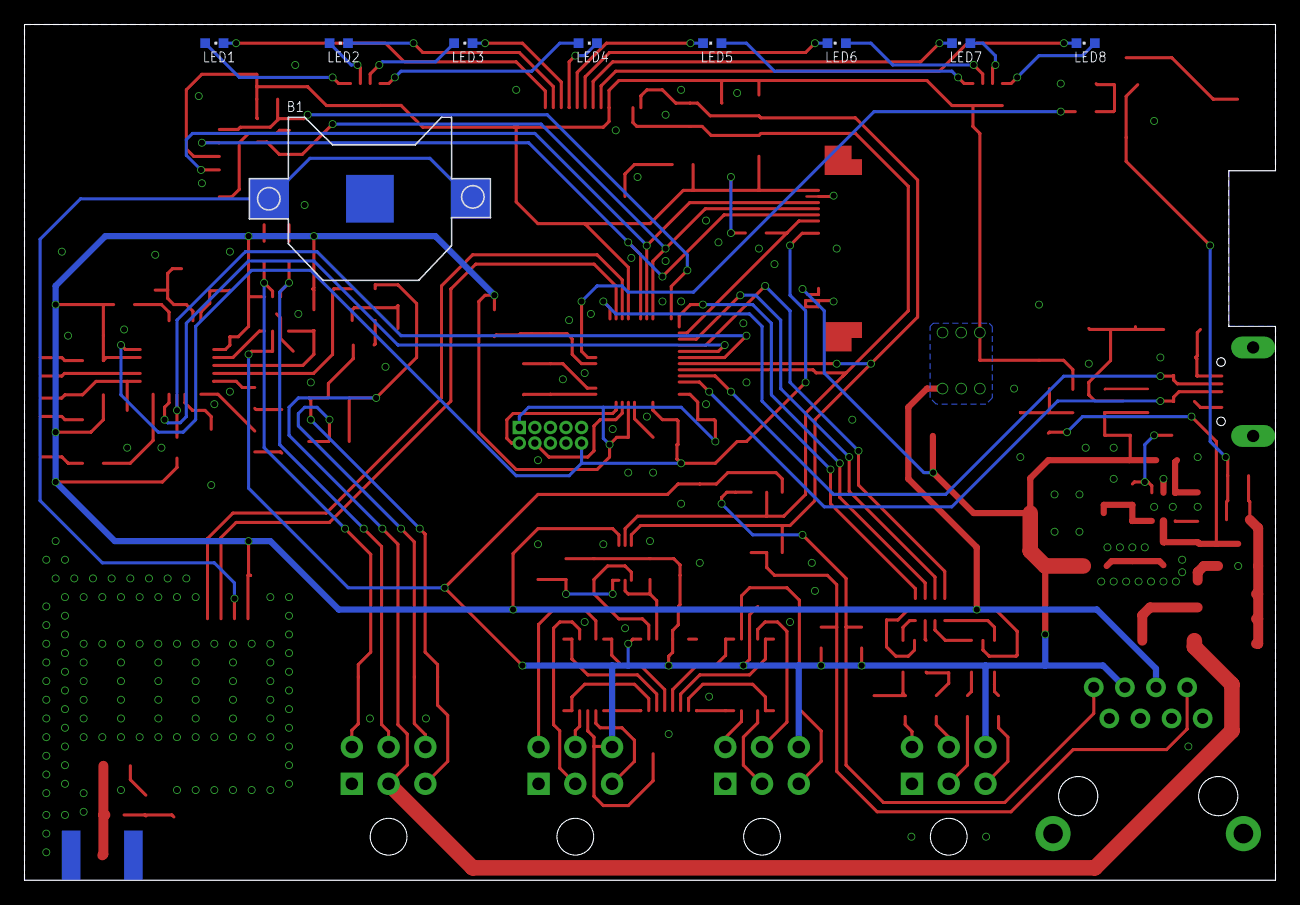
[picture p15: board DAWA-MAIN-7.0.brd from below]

Board: 2 copper layers, 102.1 x 69.8 mm, 149 parts (9 on the bottom side), 124 nets.

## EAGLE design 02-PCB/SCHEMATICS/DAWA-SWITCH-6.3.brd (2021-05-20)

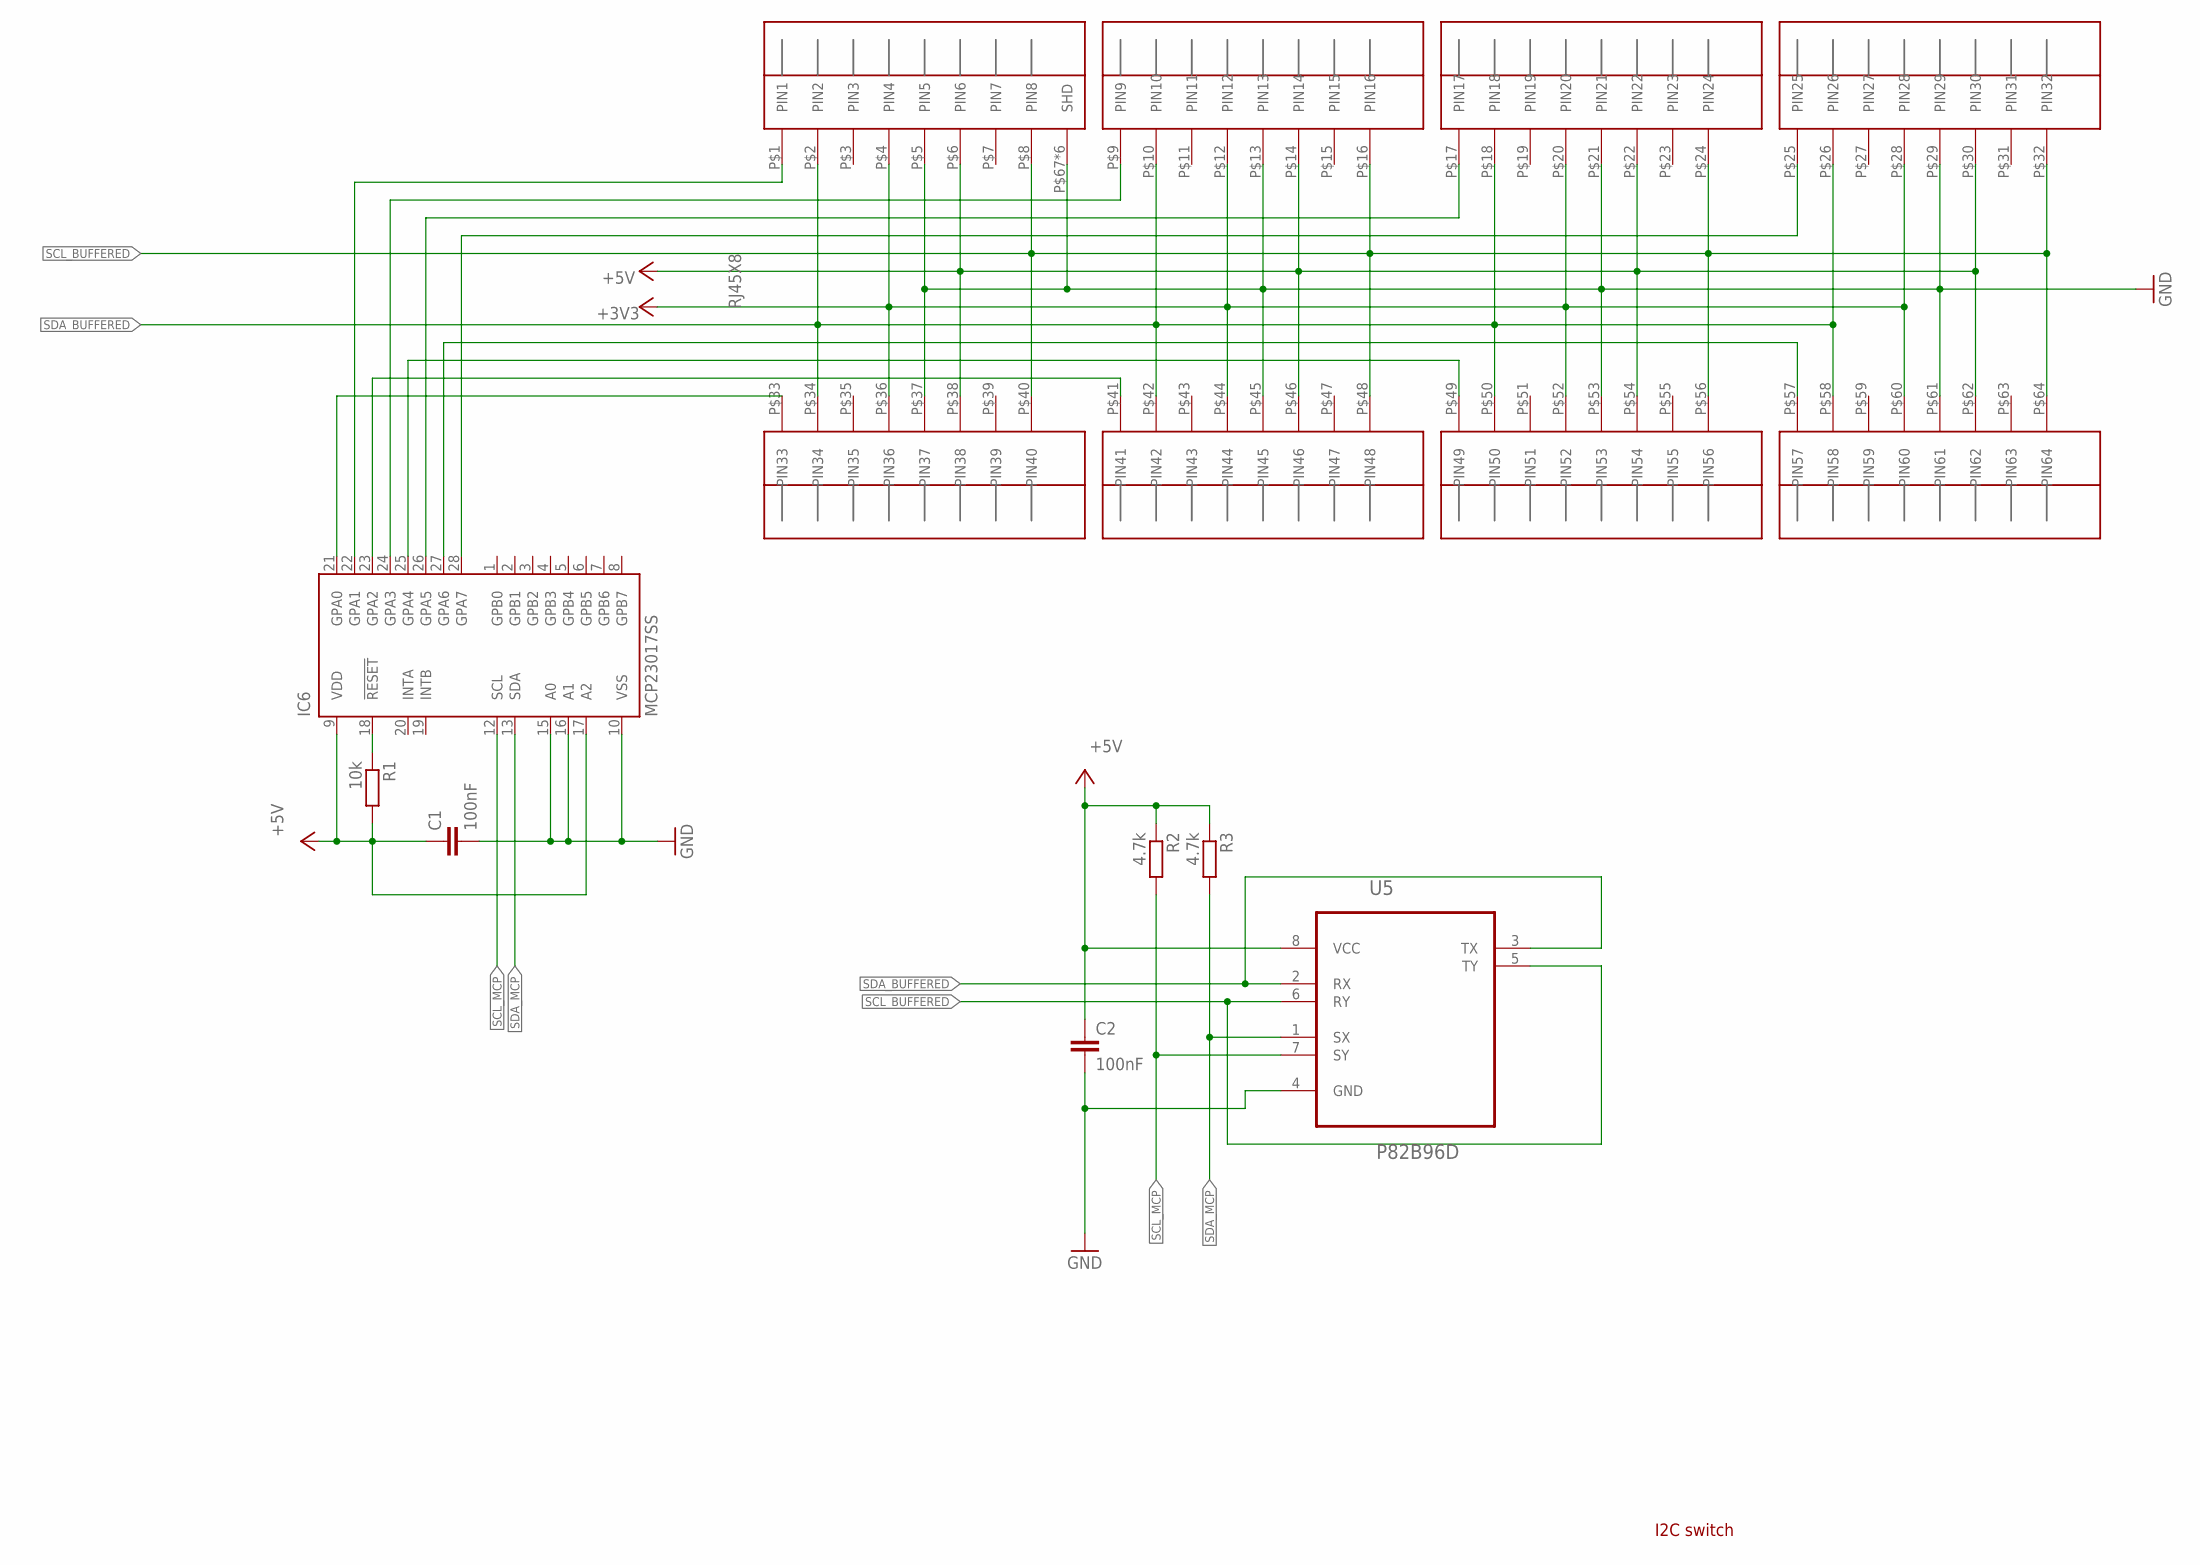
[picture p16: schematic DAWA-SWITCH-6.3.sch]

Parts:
C1, C2: 100nF; C0603
IC6: MCP23017SS; SSOP28
R1: 10k; R0603
R2, R3: 4.7k; R0603
U5: P82B96D; SOIC127P600X175-8N
U$18: RJ45X8

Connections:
+3V3: U$18.P$4 (PIN4), U$18.P$12 (PIN12), U$18.P$20 (PIN20), U$18.P$28 (PIN28), U$18.P$36 (PIN36), U$18.P$44 (PIN44), U$18.P$52 (PIN52), U$18.P$60 (PIN60)
+5V: C1.1, C2.1, IC6.9 (VDD), IC6.17 (A2), R1.2, R2.1, R3.1, U5.8 (VCC), U$18.P$6 (PIN6), U$18.P$14 (PIN14), U$18.P$22 (PIN22), U$18.P$30 (PIN30), U$18.P$38 (PIN38), U$18.P$46 (PIN46), U$18.P$54 (PIN54), U$18.P$62 (PIN62)
GND: C1.2, C2.2, IC6.10 (VSS), IC6.15 (A0), IC6.16 (A1), U5.4 (GND), U$18.P$5 (PIN5), U$18.P$13 (PIN13), U$18.P$21 (PIN21), U$18.P$29 (PIN29), U$18.P$37 (PIN37), U$18.P$45 (PIN45), U$18.P$53 (PIN53), U$18.P$61 (PIN61), U$18.P$67 (SHD), U$18.P$68 (SHD), U$18.P$69 (SHD), U$18.P$70 (SHD), U$18.P$71 (SHD), U$18.P$72 (SHD)
unnamed: IC6.28 (GPA7), U$18.P$25 (PIN25)
unnamed: IC6.26 (GPA5), U$18.P$17 (PIN17)
unnamed: IC6.24 (GPA3), U$18.P$9 (PIN9)
unnamed: IC6.22 (GPA1), U$18.P$1 (PIN1)
unnamed: IC6.21 (GPA0), U$18.P$33 (PIN33)
unnamed: IC6.23 (GPA2), U$18.P$41 (PIN41)
unnamed: IC6.25 (GPA4), U$18.P$49 (PIN49)
unnamed: IC6.27 (GPA6), U$18.P$57 (PIN57)
unnamed: IC6.18 (!RESET), R1.1
SCL_BUFFERED: U5.5 (TY), U5.6 (RY), U$18.P$8 (PIN8), U$18.P$16 (PIN16), U$18.P$24 (PIN24), U$18.P$32 (PIN32), U$18.P$40 (PIN40), U$18.P$48 (PIN48), U$18.P$56 (PIN56), U$18.P$64 (PIN64)
SCL_MCP: IC6.12 (SCL), R2.2, U5.7 (SY)
SDA_BUFFERED: U5.2 (RX), U5.3 (TX), U$18.P$2 (PIN2), U$18.P$10 (PIN10), U$18.P$18 (PIN18), U$18.P$26 (PIN26), U$18.P$34 (PIN34), U$18.P$42 (PIN42), U$18.P$50 (PIN50), U$18.P$58 (PIN58)
SDA_MCP: IC6.13 (SDA), R3.2, U5.1 (SX)

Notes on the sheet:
I2C switch

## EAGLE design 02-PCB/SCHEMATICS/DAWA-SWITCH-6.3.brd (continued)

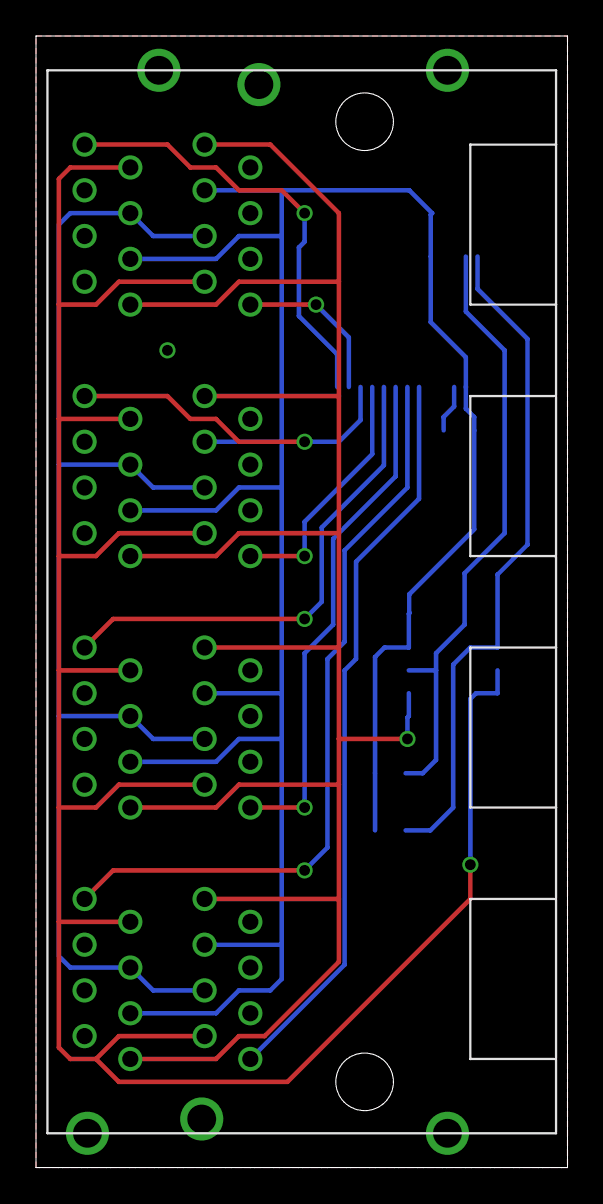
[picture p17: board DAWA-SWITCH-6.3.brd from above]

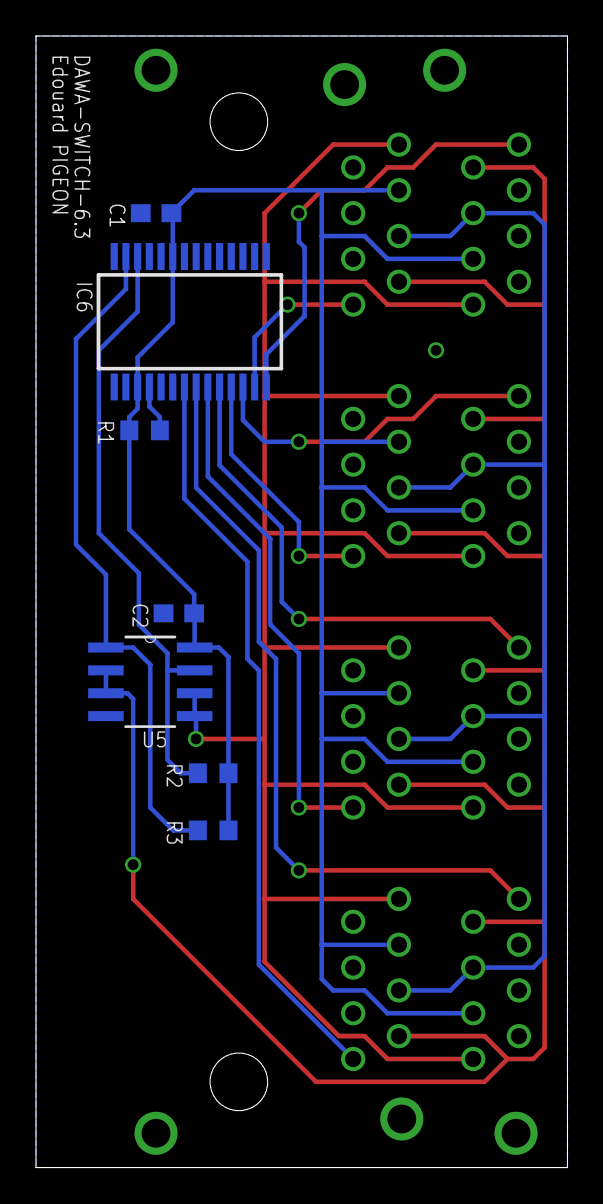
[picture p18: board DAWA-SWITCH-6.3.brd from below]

Board: 2 copper layers, 29.5 x 62.9 mm, 8 parts (7 on the bottom side), 16 nets.

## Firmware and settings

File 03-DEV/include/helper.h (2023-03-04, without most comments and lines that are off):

#define HELPER_H_
#define GEAR_CALIB_SIZE 7                            // How many gears we have
#define MAX_MLX_SIZE 6                               // Max MLX chips that could be declared (could be more but need to add object instances, just before setup())
#define FIRST_MLX_ADDRESS 0x01                       // First allocated MLX I2C address (then +1 on each discovered MLX sensor)
#define GEAR_OFFSET 200                              // Each gear has a corresponding value, this value define the interval (value - GEAR_OFFSET < measure < value + GEAR_OFFSET)
#define DEFAULT_ENDIGITALINPUTSBITS_VALUE 0b00001111 // Default enabled digital inputs
#define DEFAULT_ENANALOGINPUTSBITS_VALUE 0b00001111  // Default enabled analog inputs
#define DEFAULT_RPM_CORRECTION_RATIO 105             // RPM correction ratio (100 = no correction, 105 = x 1.05)
#define DEFAULT_RPM_FLYWHEEL_TEETH 22                // Flywheel teeth (Triumph Daytona = 22)
#define DEFAULT_SELECTED_TRACK_ID -1                 // Default selected track ID (-1 = nullTrack)
#define DEFAULT_OBD_FEATURES 0                       // Default OBD features (disabled)
#define DEFAULT_TRACK_QTY 0                          // Default number of tracks in EEPROM
#define MAX_TRACKS 50                                // Maximum number of tracks that can be handle (loaded in EEPROM and RAM)
#define TRACK_PAGINATION 6                           // Number of tracks shown in one page
#define MAX_TRACK_DISTANCE 5                         // Autoselect nearest track (unit = km)
#define EEPROM_SIZE 8192                             // EEPROM size in kBytes (not kbits !)
#define EEPROM_GENERAL_ADDR 0                        // First address on EEPROM to save general data
#define EEPROM_GEAR_CALIBRATION_ADDR 10              // First address on EEPROM to save gear calibration data
#define EEPROM_MLX_ADDR 30                           // First address on EEPROM to save MLX data
#define EEPROM_FIRST_TRACK_ADDR 40                   // First address on EEPROM to save tracks data
#define MAX_LAPS 30                                  // Max laps in an array
#define LAP_PAGINATION 8                             // Number of laps shown in one page
#define MAX_HISTORY_WHEN_RUNNING 3                   // Number of history laptime printed when running
#define TFT_DEFAULT_FONT_COLOR 0xffffffUL            // TFT default font color
#define TFT_DEFAULT_BORDER_H_SIZE 5
#define TFT_DEFAULT_BORDER_V_SIZE 1
#define TFT_BUTTON_BORDER_SIZE 5
#define TFT_BUTTON_H_SIZE 80
#define TFT_BUTTON_H2_SIZE 160
#define TFT_BUTTON_H3_SIZE 20
#define TFT_BUTTON_H4_SIZE 60
#define TFT_BUTTON_V_SIZE 30
#define TFT_BUTTON_V3_SIZE 20
#define TFT_BUTTON_H_SPACE 10
#define TFT_BUTTON_V_SPACE 10
#define TFT_HEADER_H_SPACE 30
#define TFT_HEADER_V_SPACE 30
#define TFT_HEADER_V_SPACE_HEADER 60
#define TFT_FONT_01_SIZE 12
#define TFT_FONT_01_V_SPACE 15
#define TFT_FONT_02_SIZE 13
#define TFT_FONT_02_V_SPACE 19
#define TFT_FONT_03_SIZE 14
#define TFT_FONT_03_V_SPACE 75
constexpr uint8_t inDigiBrakePin = 3; // D3, digital input
constexpr uint8_t inDigiOpt1Pin = 11; // D11, digital input
constexpr uint8_t sdCsPin = 5;        // D5, Chip Select for SDCARD on SPI bus
constexpr uint8_t mcp1Led1 = 8;       // Led 1 on MCP23017
constexpr uint8_t mcp1Led2 = 9;       // Led 2 on MCP23017
constexpr uint8_t mcp1Led3 = 10;      // Led 3 on MCP23017
constexpr uint8_t mcp1Led4 = 11;      // Led 4 on MCP23017
constexpr uint8_t mcp1Led5 = 12;      // Led 5 on MCP23017
constexpr uint8_t mcp1Led6 = 13;      // Led 6 on MCP23017
constexpr uint8_t mcp1Led7 = 14;      // Led 7 on MCP23017
constexpr uint8_t mcp1Led8 = 15;      // Led 8 on MCP23017
constexpr uint8_t powerState = A1;    // A1, power switch state (set 0 to power off)
constexpr char csvDelim = ';'; // CSV file delimiter
constexpr float rescaleGPS = 10000000.0; // We use "long" for GPS coordinates to keep precision ("float" on Arduino have only 6 decimal digits of precision) ### https://gis.stackexchange.com/questions/8650/measuring-accuracy-of-latitude-and-longitude
constexpr unsigned char ubxRate10Hz[] PROGMEM = {0x06, 0x08, 0x06, 0x00, 0x64, 0x00, 0x01, 0x00, 0x01, 0x00};
constexpr unsigned char ubxPrtConf[] PROGMEM = {0x06, 0x00, 0x14, 0x00, 0x01, 0x00, 0x00, 0x00, 0xd0, 0x08, 0x00, 0x00, 0x00, 0xc2, 0x01, 0x00, 0x07, 0x00, 0x07, 0x00, 0x00, 0x00, 0x00, 0x00}; // 115200bps
const unsigned char ubxDisableGGA[] PROGMEM = {0x06, 0x01, 0x08, 0x00, 0xF0, 0x00, 0x00, 0x00, 0x00, 0x00, 0x00, 0x01};
const unsigned char ubxDisableGLL[] PROGMEM = {0x06, 0x01, 0x08, 0x00, 0xF0, 0x01, 0x00, 0x00, 0x00, 0x00, 0x00, 0x01};
const unsigned char ubxDisableGSA[] PROGMEM = {0x06, 0x01, 0x08, 0x00, 0xF0, 0x02, 0x00, 0x00, 0x00, 0x00, 0x00, 0x01};
const unsigned char ubxDisableGSV[] PROGMEM = {0x06, 0x01, 0x08, 0x00, 0xF0, 0x03, 0x00, 0x00, 0x00, 0x00, 0x00, 0x01};
const unsigned char ubxDisableRMC[] PROGMEM = {0x06, 0x01, 0x08, 0x00, 0xF0, 0x04, 0x00, 0x00, 0x00, 0x00, 0x00, 0x01};
const unsigned char ubxDisableVTG[] PROGMEM = {0x06, 0x01, 0x08, 0x00, 0xF0, 0x05, 0x00, 0x00, 0x00, 0x00, 0x00, 0x01};
const unsigned char ubxDisableZDA[] PROGMEM = {0x06, 0x01, 0x08, 0x00, 0xF0, 0x08, 0x00, 0x00, 0x00, 0x00, 0x00, 0x01};
constexpr int32_t zone_hours = +1L;  // EST
constexpr int32_t zone_minutes = 0L; // usually zero
constexpr NeoGPS::clock_t zone_offset =
    zone_hours * NeoGPS::SECONDS_PER_HOUR +
    zone_minutes * NeoGPS::SECONDS_PER_MINUTE;
#define EU_DST
constexpr uint8_t springMonth = 3;
constexpr uint8_t springDate = 31; // latest last Sunday
constexpr uint8_t springHour = 1;
constexpr uint8_t fallMonth = 10;
constexpr uint8_t fallDate = 31; // latest last Sunday
constexpr uint8_t fallHour = 1;
#define CALCULATE_DST
constexpr static char MENU_SETUP[] PROGMEM = "SETUP";
constexpr static char MENU_SHUTDOWN[] PROGMEM = "OFF";
constexpr static char MENU_GENERAL[] PROGMEM = "GENERAL";
constexpr static char MENU_TEMP[] PROGMEM = "TEMP.";
constexpr static char MENU_OBD[] PROGMEM = "OBD";
constexpr static char MENU_ANALOG[] PROGMEM = "ANALOG";
constexpr static char MENU_DIGITAL[] PROGMEM = "DIGITAL";
constexpr static char MENU_TRACKS[] PROGMEM = "TRACKS";
constexpr static char MENU_START[] PROGMEM = "START";
constexpr static char MENU_STOP[] PROGMEM = "STOP";
constexpr static char MENU_LAPTIMES[] PROGMEM = "LAPS";
constexpr static char MENU_FAKELAP[] PROGMEM = "FAKELAP";
constexpr static char MENU_GPS[] PROGMEM = "GPS";
constexpr static char MENU_SDCARD[] PROGMEM = "SDCARD";
constexpr static char MENU_EEPROM[] PROGMEM = "EEPROM";
constexpr static char MENU_RESET_EEPROM[] PROGMEM = "RESET";
constexpr static char MENU_DEFAULT_EEPROM[] PROGMEM = "DEFAULT";
constexpr static char MENU_BACK[] PROGMEM = "BACK";
constexpr static char MENU_AUTODETECT_MLX[] PROGMEM = "AUTO DETECT";
constexpr static char MENU_IMPORT_TRACK[] PROGMEM = "IMPORT TRACKS";
constexpr static char MENU_PREVIOUS[] PROGMEM = "<<";
constexpr static char MENU_NEXT[] PROGMEM = ">>";
constexpr static char MENU_AUTOSELECT_TRACK[] PROGMEM = "AUTOSELECT";
constexpr static char MENU_BEST_LT_TRACK[] PROGMEM = "BEST TRK";
constexpr static char MENU_BEST_LT_ALL_TRK[] PROGMEM = "HoF";
constexpr static char MENU_BEST_LT_72H[] PROGMEM = "BEST 72H";
constexpr static char MENU_BEST_LT_LASTRUN[] PROGMEM = "LAST RUN";
constexpr static char LABEL_VERSION[] PROGMEM = "DAwA v7.0";
constexpr static char LABEL_KMH[] PROGMEM = "km/h";
constexpr static char LABEL_RPM[] PROGMEM = "rpm x1000";
constexpr static char LABEL_DEBUG_IS_ENABLED[] PROGMEM = "DEBUG is enabled";
constexpr static char LABEL_DAWA_INIT[] PROGMEM = "D.A.W.A. Init ...";
constexpr static char LABEL_OK[] PROGMEM = "OK";
constexpr static char LABEL_OFF[] PROGMEM = "OFF";
constexpr static char LABEL_FAILED[] PROGMEM = "FAILED";
constexpr static char LABEL_SD_OK[] PROGMEM = "SD : OK";
constexpr static char LABEL_SD_FAILED[] PROGMEM = "SD : FAILED";
constexpr static char LABEL_OBD_OK[] PROGMEM = "OBD : OK";
constexpr static char LABEL_OBD_FAILED[] PROGMEM = "OBD : FAILED";
constexpr static char LABEL_EEPROM_OK[] PROGMEM = "EEPROM : OK";
constexpr static char LABEL_EEPROM_FAILED[] PROGMEM = "EEPROM : FAILED";
constexpr static char LABEL_ADC_OK[] PROGMEM = "ADC : OK";
constexpr static char LABEL_ADC_FAILED[] PROGMEM = "ADC : FAILED";
constexpr static char LABEL_MCP1_OK[] PROGMEM = "MCP1 : OK";
constexpr static char LABEL_MCP1_FAILED[] PROGMEM = "MCP1 : FAILED";
constexpr static char LABEL_MCP2_OK[] PROGMEM = "MCP2 : OK";
constexpr static char LABEL_MCP2_FAILED[] PROGMEM = "MCP2 : FAILED";
constexpr static char LABEL_GPS_OK[] PROGMEM = "GPS : OK";
constexpr static char LABEL_READY[] PROGMEM = "READY !";
constexpr static char LABEL_TRK[] PROGMEM = "Track";
constexpr static char LABEL_TRK_UC[] PROGMEM = "TRK:";
constexpr static char LABEL_ABOUT1[] PROGMEM = "D.A.W.A.";
constexpr static char LABEL_ABOUT2[] PROGMEM = "Hw DAWA :     6.1";
constexpr static char LABEL_ABOUT3[] PROGMEM = "Hw DAWA-MPU : 6.3";
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

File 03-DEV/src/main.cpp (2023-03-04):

/**************************************************************
  DAWA 7.0 (Arduino M0 - Onboard SAMD21G)
  Bootloader have to be burned on new chip with for example Atmel ICE
  Motocycles laptimer/datalogger
  Edouard PIGEON - 2021
**************************************************************/

/**************************************************************
  TODO
  Un fichier unique pour synthèse chronos
  Lister l'historique des chronos (prédéfinir des affichages)
  LED/Shiftlight (+param)
  Alarmes (paramétrage/affichage)
  Passer trackID sur 8 bits (CSV read) - réduire empreinte EEPROM
  Nommer les inputs
  Optimisation code FT800
  Texte sous forme de constante (verifier tout le code)
  Voir EVE_cmd_dl
  OBD : turned off the adaptive timing "AT0" then reduced the time out "AT ST xx"
**************************************************************/

/*****************************************************
 * ################################################# *
 * ############## Includes ######################### *
 * ################################################# *
*****************************************************/

#include <Arduino.h>           // Arduino library
#include <SPI.h>               // SPI library
#include <Wire.h>              // I2C library
#include <extEEPROM.h>         // EEPROM library (http://github.com/PaoloP74/extEEPROM)
#include <Adafruit_MCP23X17.h> // I/O Expander MCP23017 (https://github.com/adafruit/Adafruit-MCP23017-Arduino-Library)
#include <TimeLib.h>           // Time library (https://github.com/PaulStoffregen/Time)
#include <SdFat.h>             // Greiman/SdFat library (https://github.com/greiman/SdFat)
#include <ELMduino.h>          // ELM327 OBD-II library (https://github.com/PowerBroker2/ELMduino)
#include <Adafruit_MLX90614.h> // MLX90614 Infrared temperature sensor (https://github.com/adafruit/Adafruit-MLX90614-Library)
#include <NMEAGPS.h>           // NeoGPS library (https://github.com/SlashDevin/NeoGPS)
#include <wiring_private.h>    // pinPeripheral() function, redefining SERCOM5 for serial port use
#include <helper.h>            // DAWA functions helper
#include <EVE_commands.h>      // EVE library
#include <tft.h>               // EVE library Rudolph Riedel FT800-FT813 (https://github.com/RudolphRiedel/FT800-FT813)

/**************************************************************
  EEPROM library

  EEPROM addresses used :
  1 RPM Correction Ratio (1x uint8_t)
  2 RPM Flywheel Teeth (1x uint8_t)
  44-56 Gear calibration data (7x int16_t)
  66 Enabled digital inputs (1x uint8_t)
  67 Enabled analog inputs (1x uint8_t)
  68-73 MLX I2C Address (6x uint8_t)
**************************************************************/

/*****************************************************
 * ################################################# *
 * ############## Vars definition ################## *
 * ################################################# *
*****************************************************/

// Inputs
uint16_t g_inAnaGearCalib[GEAR_CALIB_SIZE]; // Calibration values for GEAR input, each gear has a analogic value
uint8_t g_gearNCheck = 0;                   // Counter to check if gear is set to neutral
bool g_enObd;                               // Enable OBD features
uint8_t g_enDigitalInputsBits;              // Store enabled digital inputs (use binary values, ex : 10100000 > DIGI_SQR_RPM and DIGI_BRAKE enabled)
// BIT 0 = DIGI_SQR_RPM
// BIT 1 = DIGI_SQR_OPT_1
// BIT 2 = DIGI_BRAKE
// BIT 3 = DIGI_OPT_1
// BIT 4 = N/A
// BIT 5 = N/A
// BIT 6 = N/A
// BIT 7 = N/A
uint8_t g_enAnalogInputsBits; // Store enabled digital inputs (use binary values, ex : 11000000 > inAnaOpt1 and inAnaOpt2 enabled)
// BIT 0 = inAnaOpt1 (GEAR)
// BIT 1 = inAnaOpt2
// BIT 2 = inAnaOpt3
// BIT 3 = inAnaOpt4
// BIT 4 = inAnaOpt5
// BIT 5 = inAnaOpt6
// BIT 6 = inAnaOpt7
// BIT 7 = inAnaOpt8

// SD Card
File logFile;               // One line every 100ms with all detailed data
File lapFile;               // One line per lap with laptime
char g_workingFilename[64]; // Filename which is actually used

// GPS & Timing
int32_t g_lapSec, g_lapCsec; // Lap seconds and centiseconds
float g_totalDistance;       // Time To Finish Line
int8_t g_isRunning = 0;      // Running status (-1 = error, 0 = not running, 1 = run as datalogger only, 2 = run as datalogger and laptimer)
time_t g_date;               // A date

// OBD
uint32_t g_rpm;                 // RPM from OBD
uint32_t g_engineCoolantT;      // Engine coolant temperature from OBD
uint32_t g_obdTemp;             // Temp value from OBD
uint32_t g_lastObdSlowSync = 0; // OBD slow refresh rate calculation
uint32_t g_lastObdFastSync = 0; // OBD fast refresh rate calculation

// Analog inputs (ADC)
uint16_t g_anaValues[8]; // All 8 measured analogic values
char g_anaValuesChar[8]; // Analogic value converted to a single character (useful for ANA1/GEAR : N,1,2,3 ...)

// Digital inputs
uint32_t g_digValues[4]; // Digital values

// Infrared temperature sensor
uint8_t g_mlxAddresses[MAX_MLX_SIZE]; // Store each MLX I2C addresses
double g_mlxValues[MAX_MLX_SIZE];     // Store MLX values

// RPM
uint8_t g_rpmFlywheelTeeth;   // Number of flywheel teeth (configurable through setup menu)
uint8_t g_rpmCorrectionRatio; // RPM correction ratio (configurable through setup menu)

// Buttons & menu
bool g_isFakeLap = false; // Used to simulate a new lap (debug)
char g_msgLabel[255];     // Used to store on screen popup message
uint32_t g_msgDelay = 0;  // Number of ms the message is printed on screen
uint8_t g_msgType = 0;    // Display type (color : green, red or grey)

// TFT screen
uint32_t g_lastTftTouchSync = 0; // TFT refresh rate calculation
uint8_t g_lastTftPrintSync = 0;  // TFT refresh rate calculation
uint8_t g_tftScreenId = 10;      // Which screen is printed on TFT (0 = start page)

// Tracks
Track g_tracksList[MAX_TRACKS];                        // A array of TRACK_PAGINATION tracks
Track g_currentTrack;                                  // Current track (the nearest one)
Track g_nullTrack = {-1, "NO TRACK!", -1, 0, 0, 0, 0}; // A null track
int16_t g_currentTrackId;                              // Current track ID
uint8_t g_trackQty = 0;                                // Number of defined tracks
uint8_t g_trackPage = 0;                               // ID of the printed page on tracks screen
char g_trackName[16];                                  // Track name

// Laps
Lap g_lapsList[MAX_LAPS];                          // An array of MAX_LAPS laps
Lap g_currentLap;                                  // Current lap (running)
Lap g_nullLap = {0, 0, 0, 0, 0, 0, 0.00, 0, 0, 0}; // A null lap
uint8_t g_lapQty = 0;                              // Number of laps in the array "g_historyLap"
uint8_t g_lapPage = 0;                             // ID of the printed page on laps screen

// Debug data
#ifdef DEBUG
uint32_t g_dbgNow = 0;                     // used to calculate integration interval
uint32_t g_dbgSumCount = 0;                // used to control display output rate
float g_dbgDeltat = 0.0f, g_dbgSum = 0.0f; // integration interval for both filter schemes
uint32_t g_dbgLastUpdate = 0;              // used to calculate integration interval
#endif

/*****************************************************
 * ################################################# *
 * ############## Instantiate objects ############## *
 * ################################################# *
*****************************************************/

// EEPROM
extEEPROM eep(kbits_64, 1, 8); // I2C Address 0x50

// I/O Expander MCP23017
Adafruit_MCP23X17 MCP1;
Adafruit_MCP23X17 MCP2;

// SD Card
SdFat sd;

// MLX infrared temperature sensors
Adafruit_MLX90614 mlx[MAX_MLX_SIZE] = {Adafruit_MLX90614(FIRST_MLX_ADDRESS), Adafruit_MLX90614(FIRST_MLX_ADDRESS + 1), Adafruit_MLX90614(FIRST_MLX_ADDRESS + 2), Adafruit_MLX90614(FIRST_MLX_ADDRESS + 3), Adafruit_MLX90614(FIRST_MLX_ADDRESS + 4), Adafruit_MLX90614(FIRST_MLX_ADDRESS + 5)};

// GPS
NMEAGPS gps;
gps_fix fix_data;
gps_fix fix_data_prev;

// GPS
HardwareSerial &GPS_PORT = Serial5; // Use Serial5 port for GPS

// OBD2 serial port
Uart OBD2_PORT(&sercom5, 7, 6, SERCOM_RX_PAD_3, UART_TX_PAD_2); // Use serial port for OBD2 - Disable SERCOM5 (Serial + Sercom5) in [...]\.platformio\packages\framework-arduino-samd\variants\arduino_mzero\variant.cpp

// OBD2 ELMduino object
ELM327 myELM327;

/*****************************************************
 * ################################################# *
 * ############## Init./Setup ###################### *
 * ################################################# *
*****************************************************/

void setup()
{
  /**************************************************************
    I2C bus init
  **************************************************************/
  Wire.begin();
  Wire.setClock(400000);
  delay(500);

#ifdef DEBUG
  while (!DEBUG_PORT)
    ;
  DEBUG_PORT.println(LABEL_DEBUG_IS_ENABLED);
#endif

  /**************************************************************
    TFT Init
  **************************************************************/
  digitalWrite(EVE_CS, HIGH);
  pinMode(EVE_CS, OUTPUT);
  digitalWrite(EVE_PDN, HIGH);
  pinMode(EVE_PDN, OUTPUT);
  SPI.begin();                         // sets up the SPI to run in Mode 0 and 1 MHz
  SPI.setClockDivider(SPI_CLOCK_DIV2); // speed up SPI
  TFT_init();

  /**************************************************************
    Init I/O pins
  **************************************************************/
  pinMode(inDigiBrakePin, INPUT); // Digital boolean input (brake) (0v/12v)
  pinMode(inDigiOpt1Pin, INPUT);  // Digital boolean input (optional) (0v/12v)
  pinMode(sdCsPin, OUTPUT);       // Chip Select for SDCARD on SPI bus
  pinMode(powerState, OUTPUT);    // A1, power switch state (set 0 to power off)
  digitalWrite(powerState, HIGH);

  /**************************************************************
    I/O Expander 1 (Output = 8 leds)
  **************************************************************/
  if (!MCP1.begin_I2C())
  {
#ifdef DEBUG
    DEBUG_PORT.println(LABEL_MCP1_FAILED);
#endif
  }
  else
  {
#ifdef DEBUG
    DEBUG_PORT.println(LABEL_MCP1_OK);
#endif
    MCP1.pinMode(mcp1Led1, OUTPUT);
    MCP1.pinMode(mcp1Led2, OUTPUT);
    MCP1.pinMode(mcp1Led3, OUTPUT);
    MCP1.pinMode(mcp1Led4, OUTPUT);
    MCP1.pinMode(mcp1Led5, OUTPUT);
    MCP1.pinMode(mcp1Led6, OUTPUT);
    MCP1.pinMode(mcp1Led7, OUTPUT);
    MCP1.pinMode(mcp1Led8, OUTPUT);
    MCP1.digitalWrite(mcp1Led1, HIGH);
    MCP1.digitalWrite(mcp1Led2, HIGH);
    MCP1.digitalWrite(mcp1Led3, HIGH);
    MCP1.digitalWrite(mcp1Led4, HIGH);
    MCP1.digitalWrite(mcp1Led5, HIGH);
    MCP1.digitalWrite(mcp1Led6, HIGH);
    MCP1.digitalWrite(mcp1Led7, HIGH);
    MCP1.digitalWrite(mcp1Led8, HIGH);
  }

  /**************************************************************
    I/O Expander 2 (Output = 5v power for 6 devices like MLX sensors plugged on hub)
  **************************************************************/
  if (!MCP2.begin_I2C(0x24))
  {
#ifdef DEBUG
    DEBUG_PORT.println(LABEL_MCP2_FAILED);
#endif
  }
  else
  {
#ifdef DEBUG
    DEBUG_PORT.println(LABEL_MCP2_OK);
#endif
    MCP2.pinMode(0, OUTPUT);
    MCP2.pinMode(1, OUTPUT);
    MCP2.pinMode(2, OUTPUT);
    MCP2.pinMode(3, OUTPUT);
    MCP2.pinMode(4, OUTPUT);
    MCP2.pinMode(5, OUTPUT);
    MCP2.pinMode(6, OUTPUT);
    MCP2.pinMode(7, OUTPUT);
    MCP2.digitalWrite(0, HIGH);
    MCP2.digitalWrite(1, HIGH);
    MCP2.digitalWrite(2, HIGH);
    MCP2.digitalWrite(3, HIGH);
    MCP2.digitalWrite(4, HIGH);
    MCP2.digitalWrite(5, HIGH);
    MCP2.digitalWrite(6, HIGH);
    MCP2.digitalWrite(7, HIGH);
  }

  /**************************************************************
    OBD2 Init (Serial2)
  **************************************************************/
  // Trying to establish connection to OBD @921600bps (STN2100 default is 9600bps)
  OBD2_PORT.begin(921600);
  pinPeripheral(6, PIO_SERCOM);   // Pin D6 for RX
  pinPeripheral(7, PIO_SERCOM);   // Pin D7 for TX
  if (!myELM327.begin(OBD2_PORT)) // To DEBUG : if (!myELM327.begin(OBD2_PORT, true, 1000))
  {
    // @921600bps not working, probably the first time you run this program on new hardware
    // Trying @9600bps which is the default speed
    OBD2_PORT.begin(9600);
    pinPeripheral(6, PIO_SERCOM); // Pin D6 for RX
    pinPeripheral(7, PIO_SERCOM); // Pin D7 for TX
    if (myELM327.begin(OBD2_PORT))
    {
      // OBD is OK @9600bps, trying to switch to 921600bps
      myELM327.sendCommand_Blocking(OBD_STSBR_921600);
#ifdef DEBUG
      DEBUG_PORT.print(LABEL_SWITCH_2_921600);
      DEBUG_PORT.println(myELM327.payload);
#endif
      delay(75);
      OBD2_PORT.begin(921600);
      pinPeripheral(6, PIO_SERCOM); // Pin D6 for RX
      pinPeripheral(7, PIO_SERCOM); // Pin D7 for TX

      // Save new baud rate to default (NV memory) only if serial communication is successfull
      myELM327.sendCommand_Blocking(OBD_STI);
      if (strstr(myELM327.payload, OBD_STN2100) != NULL)
      {
        myELM327.sendCommand_Blocking(OBD_STWBR);
#ifdef DEBUG
        DEBUG_PORT.print(LABEL_NEW_RATE_921600);
        DEBUG_PORT.println(myELM327.payload);
#endif
      }
    }
  }
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
void loop()
{
  static uint8_t tmpComp, bitShift; // Used to compare values for enabled inputs checks
  static bool addFinishLog = false;
  static float tToFl;
  static uint32_t lastPinRead, lastOneSecSync, lastSdSync, fixCount, elapsedTime;
  static int32_t posCrossLat, posCrossLon;
  typedef enum
  {
    IDLE,
    COOLANT_TEMP,
    ENG_RPM
  } obd_pid_states;
  static obd_pid_states obd_state = IDLE;

#ifdef DEBUG
  // Here we calculate average update rate of main loop
  g_dbgNow = micros();
  g_dbgDeltat = ((g_dbgNow - g_dbgLastUpdate) / 1000000.0f);
  g_dbgLastUpdate = g_dbgNow;
  g_dbgSum += g_dbgDeltat;
  g_dbgSumCount++;
#endif

  /**************************************************************
    Get GPS frames through serial port (RX/TX)
    This is CRITICAL, data could be sent at any moment by the GPS so main loop should be executed in a minimum of time
    More information : https://github.com/SlashDevin/NeoGPS/blob/master/extras/doc/Troubleshooting.md#quiet-time-interval
  **************************************************************/
  if (gps.available(GPS_PORT))
  {
    /**************************************************************
      Read last available GPS data
    **************************************************************/
    fix_data_prev = fix_data; // Memorize previous values before next GPS fix
    fix_data = gps.read();    // Get GPS data
    adjustTime(fix_data.dateTime);
    fixCount++;

    /**************************************************************
      Read all 4 digital enabled INPUTS
    **************************************************************/
    elapsedTime = millis() - lastPinRead; // Used to have precise measures on RPM and SPEED
    lastPinRead = millis();               // Reset last pin read

    bitShift = 0b00000001;
    for (uint8_t i = 0; i < 4; i++)
    { // Read values of enabled inputs only
      tmpComp = bitShift & g_enDigitalInputsBits;
      if (tmpComp == bitShift)
      {
        switch (i)
        {
        // bit 0 : RPM;
        case 0:
          REG_TCC1_CTRLBSET = TCC_CTRLBSET_CMD_READSYNC; // Trigger a read synchronization on the COUNT register
          while (TCC1->SYNCBUSY.bit.CTRLB)
            ; // Wait for the CTRLB register write synchronization
          while (TCC1->SYNCBUSY.bit.COUNT)
            ;                              // Wait for the COUNT register read sychronization
          g_digValues[i] = REG_TCC1_COUNT; // Read TCNT1 register (timer1 counter)
          REG_TCC1_COUNT = 0x0000;         // Clear timer's COUNT value
          while (TCC1->SYNCBUSY.bit.COUNT)
            ;                                                                                              // Wait for synchronization
          g_digValues[i] = g_digValues[i] * g_rpmCorrectionRatio * 600 / elapsedTime / g_rpmFlywheelTeeth; // Ratio between pulse and rpm (22 > flywheel has 22 teeth ### 600 > with check every 100ms, RPM is by minute) ### g_rpmCorrectionRatio > *(100+corr) / elapsedTime) > if we read counter @101ms or 102ms values should be adjusted
          break;
        // bit 1 : SQR1;
        case 1:
          REG_TCC0_CTRLBSET = TCC_CTRLBSET_CMD_READSYNC; // Trigger a read synchronization on the COUNT register
          while (TCC0->SYNCBUSY.bit.CTRLB)
            ; // Wait for the CTRLB register write synchronization
          while (TCC0->SYNCBUSY.bit.COUNT)
            ;                              // Wait for the COUNT register read sychronization
          g_digValues[i] = REG_TCC0_COUNT; // Read TCNT0 register (timer0 counter)
          REG_TCC0_COUNT = 0x0000;         // Clear timer's COUNT value
          while (TCC0->SYNCBUSY.bit.COUNT)
            ;                                                  // Wait for synchronization
          g_digValues[i] = g_digValues[i] * 100 / elapsedTime; // Ratio is set to 1 so no maths ### (* 100 / elapsedTime) > if we read counter @99ms, 101ms or 102ms values should be adjusted
          break;
        // bit 2 : DIG1;
        case 2:
          g_digValues[i] = digitalRead(inDigiBrakePin); // Read "inDigiBrakePin" (pin is plugged on the "+" of the stop light)
          break;
        // bit 3 : DIG2;
        case 3:
          g_digValues[i] = digitalRead(inDigiOpt1Pin); // Read "inDigiOpt1Pin"
          break;
        }
      }
      bitShift = bitShift << 1;
    }

    /**************************************************************
      Read analog enabled INPUTS
    **************************************************************/
    readAdcValues(); // It takes time to read all values (one voltage conversion = 12.2ms !)
    formatAdcValues();

    /**************************************************************
      Sync files on SDcard every 300 fixes (300x100ms = 30sec) to avoid dataloss on power failure
    **************************************************************/
    if (g_isRunning >= 1 && (fixCount - lastSdSync >= 300))
    {
      lastSdSync = fixCount;
      SdFile::dateTimeCallback(dateTimeSd);
      logFile.sync();
      if (g_isRunning == 2)
      {
        lapFile.sync();
      }
    }

    /**************************************************************
      1 second loop (every 10 fixes > 10x100ms = 1sec), could be used for :
      - Get values with a low refresh rate like ambiant temperature
      - Printing debug information
      - ...
    **************************************************************/
    if (fixCount - lastOneSecSync >= 10)
    {
      lastOneSecSync = fixCount;
#ifdef DEBUG
      DEBUG_PORT.print("rate = ");
      DEBUG_PORT.print((float)g_dbgSumCount / g_dbgSum, 0);
      DEBUG_PORT.println(" Hz");
      g_dbgSumCount = 0;
      g_dbgSum = 0;
#endif

      /**************************************************************
        Read and store MLX temperature in array
      **************************************************************/
      for (uint8_t i = 0; i < MAX_MLX_SIZE; i++)
      {
        if (g_mlxAddresses[i] != 0x00)
        {
          g_mlxValues[i] = mlx[i].readObjectTempC();
        }
      }
    }

    /**************************************************************
      If laptimer is running :
      - Calculate distances, laptime with GPS data
      - Log data on SDcard

      If laptimer is NOT running :
      - N/A
    **************************************************************/
    if (g_isRunning >= 1)
    {
      if (g_isRunning == 2) // Laptimer and datalogger
      {
        // Calculate total distance (for SeriousRacing compatibility)
        g_totalDistance += gpsDistance(fix_data_prev.latitudeL(), fix_data_prev.longitudeL(), fix_data.latitudeL(), fix_data.longitudeL());

        // Check if we pass the finishline (2x2 coordinates for finish line points + 2x2 coordinates for last position + position now)
        if (segIntersect(fix_data.latitudeL(), fix_data.longitudeL(), fix_data_prev.latitudeL(), fix_data_prev.longitudeL(), g_currentTrack.trackFlineLat1, g_currentTrack.trackFlineLon1, g_currentTrack.trackFlineLat2, g_currentTrack.trackFlineLon2, posCrossLat, posCrossLon) || g_isFakeLap == true)
        {
          // Debug button to simulate finish line crossing
          if (g_isFakeLap == true)
          {
            g_isFakeLap = false;
            tToFl = random(0, 9) / 100.00; // Random value to simulate Time To Finish Line (TimeToFinishLine is always < 0.10 sec as there is a GPS fix every 0.10 sec !)
          }
          else
          {
            // Calculate Time To Finish Line (from last know position by GPS just before crossing the finish line / format : sss.ms) ### tToFl = (distance between previous position and finish line (Ex : 0.00112km) / distance between previous position and actual position (Ex : 0.00254km)) * (time of actual fix - time of previous fix)
            tToFl = (gpsDistance(fix_data_prev.latitudeL(), fix_data_prev.longitudeL(), posCrossLat, posCrossLon) / gpsDistance(fix_data.latitudeL(), fix_data.longitudeL(), fix_data_prev.latitudeL(), fix_data_prev.longitudeL())) * ((fix_data.dateTime.hours * 3600 + fix_data.dateTime.minutes * 60 + fix_data.dateTime.seconds + fix_data.dateTime_cs / 100.00) - (fix_data_prev.dateTime.hours * 3600 + fix_data_prev.dateTime.minutes * 60 + fix_data_prev.dateTime.seconds + fix_data_prev.dateTime_cs / 100.00));
          }
          // Add "Time to finish line (tToFl)" to the last known Epoch Time (fix_data_prev)
          timeToFinishLineCalculation(tToFl, fix_data_prev.dateTime, fix_data_prev.dateTime_cs, g_currentLap.lapEndTimestampS, g_currentLap.lapEndTimestampCs);
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

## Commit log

2021-05-20 First commit
    Work in progress
    [DAWA-IRSENSOR-6.3.GBL, DAWA-IRSENSOR-6.3.GBO, DAWA-IRSENSOR-6.3.GBP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]
2021-10-10 Ublox NEO-M8Q
    [DAWA7.xlsx]
2021-10-31 multiple updates
    multiple updates
    [DAWA7.xlsx]
2023-03-04 Libs major update
    Use BusIO from Adafruit, test and update all libs to latest versions.
    [TRACKS.csv]

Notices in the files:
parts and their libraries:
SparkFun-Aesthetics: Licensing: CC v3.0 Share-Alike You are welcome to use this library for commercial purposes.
